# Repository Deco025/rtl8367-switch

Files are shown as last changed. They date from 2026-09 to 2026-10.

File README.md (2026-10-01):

# RTL8367 Switch

**RTL8367RB 五口千兆非网管交换机**





> An open-source five-port gigabit Ethernet switch built around the Realtek RTL8367RB. It is unmanaged: the
> chip boots from strap pins and needs no MCU. Each port has a discrete Pulse H5007NL magnetics module, a shielded RJ45
> and two status LEDs. A 12 V input feeds two on-board bucks, 3.3 V (TPS54331) and 1.1 V (TPS62130A).
> The board is a compact 100 × 72 mm, 4-layer KiCad 10 design, assembled on both sides, with complete fabrication
> outputs.

| 正面（网口一侧） | 背面（电源一侧） |
|---|---|
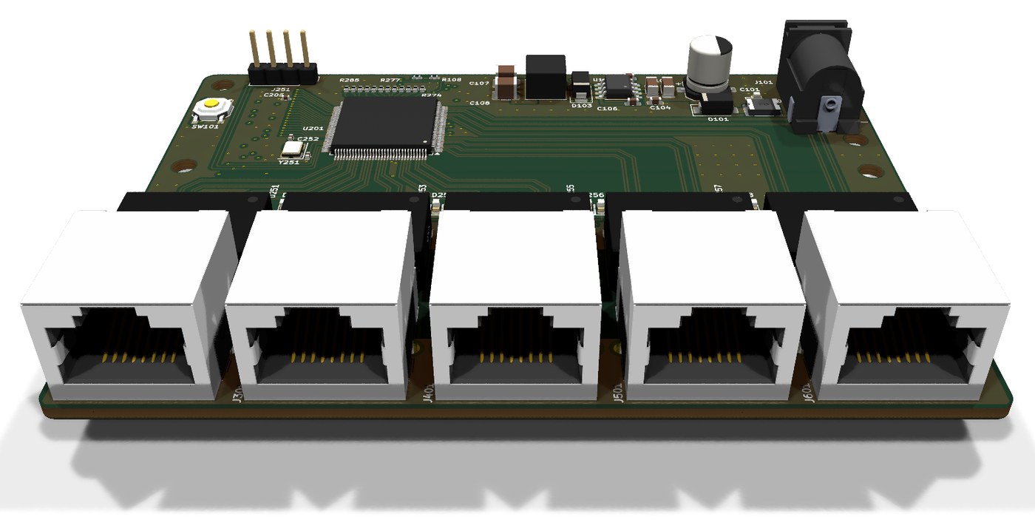
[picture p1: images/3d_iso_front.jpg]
front
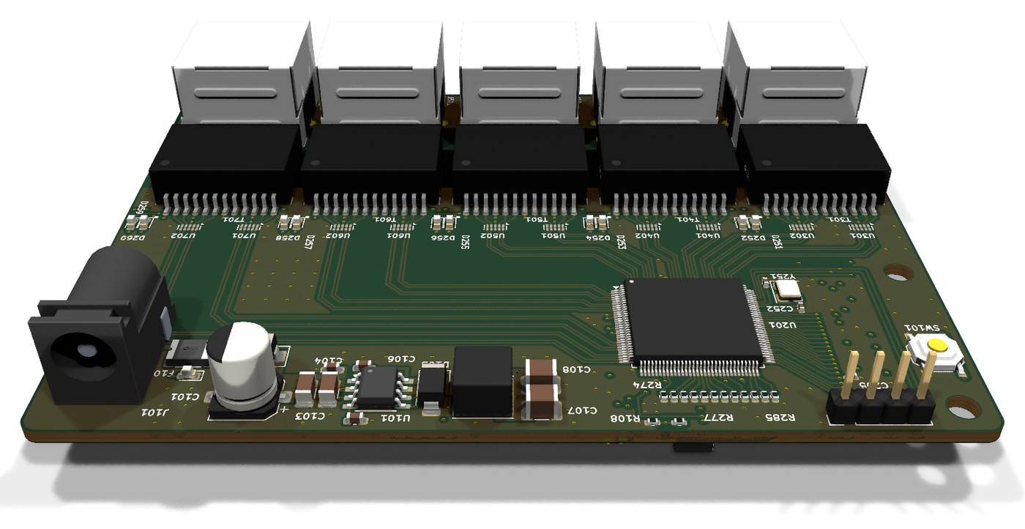
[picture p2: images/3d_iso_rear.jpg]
rear
|  |  |

### PCB 走线

| 顶层 F.Cu | 底层 B.Cu（从背面看） |
|---|---|
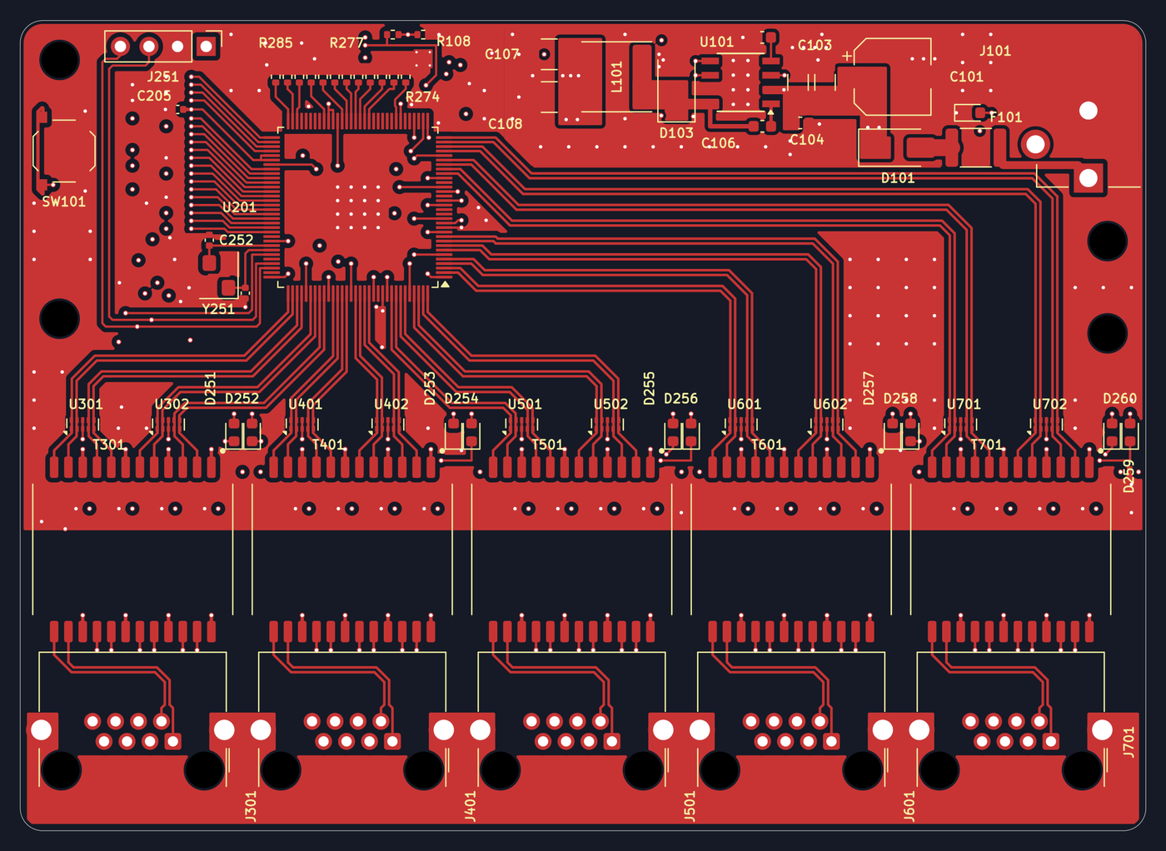
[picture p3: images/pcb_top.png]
top copper
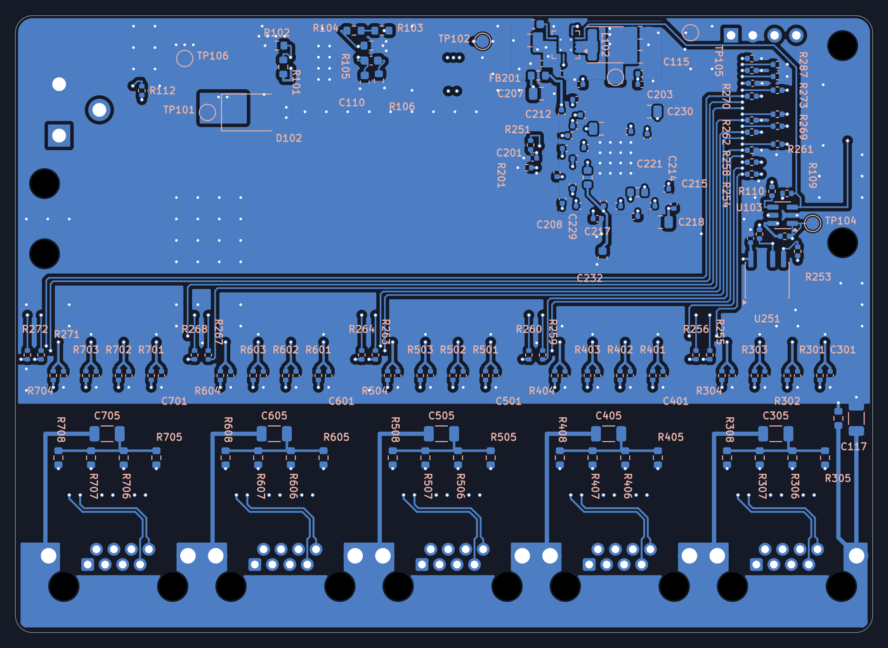
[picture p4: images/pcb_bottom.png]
bottom copper
|  |  |

第 2 层整层是地，第 3 层是电源分区；图里只画了两个外层。

### 前代样机

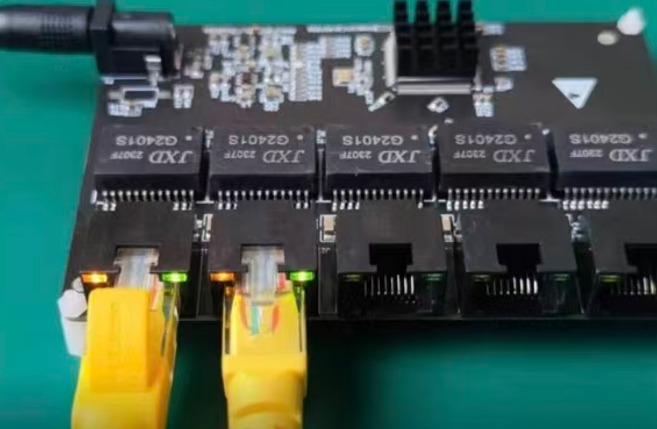
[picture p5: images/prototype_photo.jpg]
前代样机实物


这是本设计的前代样机，已经搭建并通电运行，图中两个网口接线后链路灯亮起。v0.1 在它的基础上重新设计，网络变压器从 JXD G2401S 换成了 Pulse H5007NL。上面的渲染图和走线图都是 v0.1。

---

## 目录

- [主要指标](#主要指标)
- [系统结构](#系统结构)
- [仓库结构](#仓库结构)
- [打开工程](#打开工程)
- [打样与装配](#打样与装配)
- [设计要点](#设计要点)
- [设计检查与装配注意事项](#设计检查与装配注意事项)
- [许可证](#许可证)
- [致谢](#致谢)

## 主要指标

| 项 | 值 |
|---|---|
| 交换芯片 | Realtek RTL8367RB-VB-CG（LQFP-128，带散热焊盘） |
| 端口 | 5 × 10/100/1000BASE-T，RJ45 带屏蔽壳 |
| 管理 | 非网管，靠 strap 引脚配置；预留 SMI 调试口（J251）和 EEPROM 位置（默认不贴） |
| 网络变压器 | Pulse H5007NL × 5（每口一颗，分立） |
| 指示灯 | 每口一绿一黄，外加一颗电源灯 |
| 输入 | 12 V DC，5.5 × 2.1 mm 插座（CUI PJ-102AH） |
| 输入保护 | 自恢复保险丝 0.75 A（1812L075/33DR）、防反接肖特基 SS34、TVS SMBJ15A |
| 3.3 V | TPS54331 降压，6.8 µH，SS34 续流 |
| 1.1 V（芯片核心） | TPS62130A 降压，2.2 µH，放在背面，紧靠芯片 |
| 复位 | TPS3808G30 监控 3.3 V，带手动复位按键 |
| 时钟 | 25 MHz 晶体 |
| PCB | 100 × 72 mm，4 层，1.58 mm，嘉立创叠层 JLC04161H-3313A（外层 1 oz，内层 0.5 oz） |
| 装配 | 双面贴片：正面 56 个、背面 129 个，共 185 个 |

## 系统结构

```mermaid
flowchart LR
    DC[12 V 输入<br/>保险丝 · 防反接 · TVS] --> B1[TPS54331<br/>3.3 V]
    B1 --> B2[TPS62130A<br/>1.1 V 核心]
    B1 --> FB[磁珠滤波<br/>3.3 V / 1.1 V 模拟与 PLL]
    B1 --> RST[TPS3808<br/>复位监控]
    B2 --> SW
    FB --> SW
    RST --> SW
    X[25 MHz 晶体] --> SW[RTL8367RB<br/>5 口千兆交换]
    SW -- MDI × 4 对 --> T[H5007NL × 5<br/>网络变压器]
    T --> J[RJ45 × 5<br/>Bob Smith 终端到 CHASSIS]
    SW --> LED[LED × 10]
```

- 5 个网口都用芯片内置的 PHY，MDI 从芯片直连变压器，中间没有其他器件。
- 变压器芯片侧的中心抽头各接 0.1 µF 到地，另外预留一个 0 Ω 到 +3V3A 的位置（默认不贴）。
- 线缆侧中心抽头各经 75 Ω 汇到一点，再经 1 nF / 2 kV 接屏蔽地 CHASSIS（Bob Smith 终端）。CHASSIS 与 GND 之间有一颗 1 nF 电容。
- 每对差分线旁预留了 ESD 保护（TPD4E02B04，默认不贴）。

更完整的说明见 [docs/design.md](docs/design.md)。

## 仓库结构

```
.
├── rtl8367-switch.kicad_pro   KiCad 工程
├── *.kicad_sch                原理图：根页 + 电源、芯片供电、芯片控制、5 个网口
├── rtl8367-switch.kicad_pcb   PCB
├── lib/                       工程自带的符号和封装（RTL8367RB、H5007NL、RJ45）
├── fab/                       生产文件（Gerber zip、BOM、坐标、装配图、DRC 报告）
├── 3dmodels/                  第三方 3D 模型的来源清单（模型文件不随仓库分发）
├── docs/
│   ├── design.md              设计说明
│   └── schematics/            原理图 PDF（不装 KiCad 也能看）
├── images/                    渲染图和走线图
├── CHANGELOG.md
└── LICENSE                    CERN-OHL-S-2.0
```

## 打开工程

1. 安装 [KiCad](https://www.kicad.org/) **10.0** 或更新版本。
2. 打开 `rtl8367-switch.kicad_pro`。RTL8367RB、H5007NL 和 RJ45 的符号与封装在 `lib/` 里，工程的库表已经指向它们；其余来自 KiCad 官方库。
3. **3D 模型（可选）**：有 6 种器件的 3D 模型不在 KiCad 官方库里，版权也不允许随仓库再分发。按 [3dmodels/README.md](3dmodels/README.md) 下载到 `3dmodels/`，3D 查看器（`Alt+3`）里就能看到完整外观。不下载也不影响原理图、PCB 和生产文件。

## 打样与装配

生产文件已经导出好，坐标原点在板的左上角：

| 用途 | 文件 |
|---|---|
| 上传给板厂 | [`fab/rtl8367-switch-gerber.zip`](fab/rtl8367-switch-gerber.zip) |
| 物料清单 | [`fab/rtl8367-switch-bom.csv`](fab/rtl8367-switch-bom.csv) |
| 贴片坐标（两面） | [`fab/rtl8367-switch-pos.csv`](fab/rtl8367-switch-pos.csv) |
| 装配图（第 1 页正面，第 2 页背面镜像） | [`fab/rtl8367-switch-assembly.pdf`](fab/rtl8367-switch-assembly.pdf) |
| 下单参数 | [`fab/README.md`](fab/README.md) |

下单要点：

- 4 层，1.6 mm，FR4，**叠层选 JLC04161H-3313A**。差分线的线宽线距是按这个叠层算的 100 Ω，换叠层要重算。
- 最小线宽 / 线距 0.2 / 0.15 mm，过孔 0.45 / 0.3 mm 和 0.6 / 0.3 mm。U102 封装自带 0.2 mm 的散热孔，请确认板厂能做。
- 双面贴片，背面也有器件（大多是去耦电容和上下拉电阻）。
- 变压器之后（线缆侧）的地和电源平面是有意挖空的，保证隔离间距，不要让板厂“补铜”。
- 为了版面整洁，丝印上放不下的一些小阻容位号只保留在装配层（Fab），焊接时请对照装配图。

## 设计要点

- **MDI 直通**：变压器的通道在原理图里重新分配过，芯片到变压器的 20 对差分线全部在顶层直走，不打孔、不交叉，下面是完整的地层。线对的顺序和极性调整放在变压器之后、网口下方那一小段。千兆和 10M 模式下，芯片会自动纠正极性；100M 模式对极性不敏感。
- **电源分区**：第 3 层在芯片下方分成 1.1 V 核心、1.1 V 模拟、3.3 V 模拟几块，其余是 3.3 V 主电源；1.1 V PLL 经磁珠单独供电。每个电源脚旁打一个过孔，直通背面的去耦电容。
- **两个降压电源分开放**：3.3 V 在正面右后角，开关节点铜皮只包芯片 SW 脚、续流二极管和电感，离最近的差分线约 4.6 mm；1.1 V 在背面，紧挨芯片，输入环路（PVIN–C112–PGND）在背面就地闭合，输出经过孔直接进第 3 层的核心电源区。两路的反馈分压器和各自的开关节点之间都隔着两层平面。
- **隔离与屏蔽**：变压器之后（线缆侧）不铺地和电源平面，四个线对分走四层，和芯片侧之间留隔离带；网口屏蔽壳和 Bob Smith 终端单独接 CHASSIS 铺铜。外层地铺铜与差分线保持间距，并用缝合过孔连到地层。

详见 [docs/design.md](docs/design.md)。

## 设计检查与装配注意事项

原理图 ERC 0，PCB DRC 0 错误、0 未连接，原理图与 PCB 一致。装配和调试时请留意：

1. **芯片侧中心抽头**：默认每个抽头接 0.1 µF 到地，同时预留了接 +3V3A 的 0 Ω 位置（接法参考同厂 RTL8211E 的布局指南），可按需要切换。
2. **默认转发配置和 LED 功能**由 strap 决定，可以通过 J251 的 SMI 口读写寄存器确认和调整。
3. **RJ45 的 1 脚方向**请在焊接前对照实物核对。
4. **绿色 LED** 正向压降约 2.8 V，470 Ω 限流下约 1 mA；想要更亮可以减小限流电阻。
5. **复位门限**为 2.79 V，偏低的门限用于避免上电时卡在复位里。
6. **DC 插座**（CUI PJ-102AH）请在下单前按厂家规格书确认货源和额定值。

欢迎提交 Issue 反馈问题或改进建议。

## 许可证

本项目的硬件设计文件（原理图、PCB、生产文件、文档）采用
**[CERN Open Hardware Licence Version 2 – Strongly Reciprocal (CERN-OHL-S-2.0)](LICENSE)**。

简单说：可以自由使用、学习、修改、生产和销售；但如果你发布修改后的设计，或者销售基于它的产品，必须用同样的许可证公开对应的设计源文件。

第三方封装、符号和 3D 模型各自遵循其原始许可，不在本许可证范围内。

## 致谢

- [KiCad](https://www.kicad.org/) 及其官方符号 / 封装 / 3D 库。
- 器件 3D 模型的来源见 [3dmodels/SOURCES.md](3dmodels/SOURCES.md)。

欢迎通过 Issue 反馈问题或提出改进。

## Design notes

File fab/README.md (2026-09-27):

# 生产文件

由 `kicad-cli` 从 `rtl8367-switch.kicad_pcb` 导出，坐标原点 = 板左上角（钻孔/贴片原点）。

## 下单参数

| 项 | 值 |
|---|---|
| 层数 | 4 层 |
| 板厚 | 1.6 mm（叠层实际 1.58 mm），FR4 |
| 叠层 | 嘉立创 **JLC04161H-3313A**：F.Cu / 3313 × 2 / In1（地）/ 1.065 mm 芯板 / In2（电源分区）/ 3313 × 2 / B.Cu。**内层顺序不要调换** |
| 铜厚 | 外层 1 oz，内层 0.5 oz |
| 阻抗 | MDI 差分 100 Ω：0.226 / 0.203 mm（按上面的叠层计算） |
| 尺寸 | 100 × 72 mm |
| 表面处理 | 无铅喷锡 |
| 阻焊 / 丝印 | 绿油 / 白字 |
| 过孔 | 盖油 |
| 最小线宽 / 间距 | 0.2 / 0.15 mm |
| 过孔（外径/孔径） | 0.45/0.3（296 个）、0.6/0.3（69 个） |
| 焊盘孔 | PTH 0.2 mm（U102 封装自带的散热孔，4 个）、0.3 / 0.9 / 1.0 / 1.6 / 1.8 mm；NPTH 3.2 mm（4 个安装孔）、3.25 mm（网口定位柱） |
| 贴片 | 双面：正面 56 个，背面 129 个 |

0.2 mm 的散热孔和 0.15 mm 的间距，下单前请对照所选板厂的工艺能力确认。

## 文件

- `rtl8367-switch-gerber.zip`：上传用，含 11 层 Gerber（X2）、PTH/NPTH 分开的 Excellon 钻孔、`.gbrjob`。
- `gerber/`：同上的散文件，另有钻孔分布图 PDF。
- `rtl8367-switch-bom.csv`：按 值 + 耐压 + 封装 合并；默认不贴的器件（ESD 预留位、EEPROM、中心抽头的 0 Ω 选项等）、安装孔和测试点不在表里。
- `rtl8367-switch-pos.csv`：两面的贴片坐标（mm，原点在板左上角）。用嘉立创贴片时需要按其模板改列名并补立创料号，料号见 [docs/design.md](../docs/design.md)。
- `rtl8367-switch-assembly.pdf`：装配图。第 1 页正面，第 2 页背面（镜像）。丝印上放不下而隐藏的小阻容位号都在这里。
- `rtl8367-switch-drc.rpt`：DRC 报告，0 错误、0 未连接。唯一一条警告是 J101 与库里的封装不一致：DC 插座伸出板边，超出板边的丝印线被有意删掉了。

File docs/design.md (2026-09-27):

# RTL8367 Switch 设计说明

本文记录 v0.1 的设计依据与取舍。

## 1. 关键器件

| 用途 | 型号 | 立创料号 |
|---|---|---|
| 交换芯片 | RTL8367RB-VB-CG（E-Pad LQFP-128） | C2761412 |
| 12 V → 3.3 V | TPS54331DDA + SS34 续流 + 6.8 µH | C90761 |
| 3.3 V → 1.1 V | TPS62130ARGTR + 2.2 µH | C337502 |
| 复位监控 | TPS3808G30DBVR（门限 2.79 V） | C189211 |
| 网络变压器 × 5 | Pulse H5007NL | C6384935 |
| RJ45 × 5 | Ckmtw R-RJ45R08P-B000（无灯，带屏蔽） | C386756 |
| 25 MHz 晶体 | YXC X322525MOB4SI，CL 12 pF | C9006 |
| 绿色 LED × 6 | Lite-On LTST-C193TGKT-5A | C12065 |
| 黄色 LED × 5 | KENTO KT-0603Y | C2287 |
| 输入保护 | 1812L075/33DR、SS34、SMBJ15A | C151170、C8678、C83846 |
| DC 插座 | CUI PJ-102AH（5.5 × 2.1 mm） | 采购前请确认 |

没有选 RTL8367S，是因为 RB 的热阻低得多：θJA 16.5 °C/W，S 是 45 °C/W。

## 2. 供电

```
12 V ─ F101 ─ D101（防反接）─ VIN ─┬─ D102 TVS
                                   └─ TPS54331 ─ +3V3 ─┬─ TPS62130A ─ +1V1（核心）─┬─ FB202 ─ +1V1A
                                                       │                           └─ FB203 ─ +1V1P
                                                       ├─ FB201 ─ +3V3A
                                                       └─ TPS3808 复位监控、LED、EEPROM
```

- 复位：TPS3808 监控 +3V3，1.1 V 降压的 PG、手动复位按键和监控器的 MR 接在同一个网络上，任何一个拉低都会让芯片复位。
- 3.3 V 降压放在正面右后角，按电流方向从右到左排列：插座 → 保险丝 → 防反接二极管 → 输入电容 → TPS54331 → 续流二极管 → 电感 → 输出电容。
  - 铺铜：VIN、SW、输出各一块。SW 铜皮只包芯片 SW 脚、续流二极管和电感。
  - 自举电容跨在芯片下方，两端分别对着 BOOT 脚和 SW 脚。
  - 输入电容、续流二极管、输出电容的地端都就近打一排过孔到第 2 层。
- 1.1 V 降压（TPS62130A，2.5 MHz）放在背面，紧挨芯片。
  - SW2、+1V1、+3V3 各有一小块铺铜，外加一块局部地铺铜，输入环路 PVIN–C112–PGND 在背面就地闭合。
  - 输出经电感下方的过孔进入第 3 层的 +1V1 区。
  - 反馈分压器放在正面板边，VOS 和分压器上端在输出过孔处同点采样。

## 3. 叠层与规则

| 层 | 用途 | 厚度 |
|---|---|---|
| F.Cu | 信号：MDI 全部在这层；大件 | 1 oz |
| 预浸料 | 3313 × 2 | 0.107 + 0.0994 mm |
| In1.Cu | 整层地（芯片侧） | 0.5 oz |
| 芯板 | | 1.065 mm |
| In2.Cu | 电源分区 | 0.5 oz |
| 预浸料 | 3313 × 2 | 0.0994 + 0.107 mm |
| B.Cu | 慢信号、去耦电容、1.1 V 降压 | 1 oz |

- 叠层是嘉立创 JLC04161H-3313A，总厚 1.58 mm。
- MDI 按 100 Ω 差分设计：线宽 0.226 mm、线距 0.203 mm，由嘉立创阻抗计算器按这个叠层算出。
- 最小线宽 0.2 mm；芯片引脚间距只有 0.15 mm，所以电源网络的间距设为 0.15 mm。
- 过孔 0.45 / 0.3 mm；缝合孔 0.6 / 0.3 mm。

## 4. 布局

- 5 个网口沿前边排列，间距 19.5 mm，板宽由此决定。
- 每个网口正后方是它的变压器，变压器后面是这个口的两颗 LED；芯片侧中心抽头的电容在变压器后面的背面，线缆侧的 Bob Smith 电阻和电容在变压器与网口之间的背面。
- 交换芯片居中，在变压器后面，晶体在芯片左侧，电源在后边。
- 双面贴片：大件在正面；去耦电容、上下拉电阻、LED 限流电阻、中心抽头电容、终端电阻和测试点放在背面。

## 5. MDI

- **芯片到变压器**：在原理图里重新分配了每个口变压器 4 个通道和芯片 4 对差分线的对应关系，使 20 对线从芯片引脚到变压器全部在顶层直走，不打孔、不交叉，下面是完整的第 2 层地。
- **线对顺序和极性**：变压器之后、网口下方那一段做换序。
  - 为了不交叉，每对线在网口侧的正负标号做了对调。
  - RTL8367RB 在 1000BASE-T 和 10BASE-T 下会自动纠正线对极性，100BASE-TX 对极性不敏感（数据手册 Pre-0.92，§8.10）。
- **线缆侧**：
  - 四个线对分走四层（A 顶层、B 第 2 层、C 第 3 层、D 底层），直接接到网口的通孔脚。
  - 这一段的地和电源平面全部挖空，与芯片侧之间留隔离带。
- **中心抽头**：
  - 芯片侧每个抽头 0.1 µF 到地，并预留一个 0 Ω 到 +3V3A 的位置（默认不贴）。
  - 线缆侧每个抽头 75 Ω 汇到一点，经 1 nF / 2 kV 接 CHASSIS（Bob Smith 终端）。
- **ESD**：每对线旁预留了 TPD4E02B04（直通式，默认不贴），走线直接穿过它的焊盘。

## 6. 电源完整性

- 第 2 层在芯片侧是整层地。第 3 层在芯片下方分出几个区：
  - +1V1 核心区，并伸出一条 2 mm 宽的“手指”到背面的 1.1 V 降压；
  - +1V1A 环；
  - +3V3A 环（另有一条支路给中心抽头的预留位）；
  - 其余是 +3V3 主电源。
- 芯片的每个电源脚旁都打一个过孔，直通背面的 0402 去耦电容，电容的地端再就近打孔。
- 散热焊盘下的 16 个过孔同时是芯片的主要地回路，背面这块区域不放器件。
- 外层在平面范围内铺地，离其他铜 0.4 mm，并打缝合过孔连到第 2 层。

## 7. 时钟与控制

- 25 MHz 晶体离 XTAL 脚很近，两颗负载电容直接贴在晶体焊盘旁，晶体下方的焊盘之间有地连接。
- 扩展口（RGMII）引脚的下拉电阻排成一行，放在芯片后方。
- 10 路 LED 信号在背面汇成一组总线，到各口再分出去。
- J251 引出 SMI 的时钟和数据线，加上 3.3 V 和地，用来读写寄存器。
- EEPROM（AT24C256C）的位置已预留，默认不贴。

## 8. 装配与调试注意事项

见 [README](../README.md#设计检查与装配注意事项)。

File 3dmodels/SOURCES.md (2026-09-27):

# 3D 模型来源

下载日期 2026-09-27。来源页没有写许可说明的，标为“来源页未注明”。

| 文件 | 器件 | 来源 | 立创料号 | 许可 |
|---|---|---|---|---|
| `R-RJ45R08P-B000.step` | Ckmtw R-RJ45R08P-B000 | https://www.lcsc.com/product-detail/Ethernet-Connectors-Modular-Connectors-RJ45-RJ11-Ckmtw-R-RJ45R08P-B000_C386756.html（EasyEDA 3D 导出） | C386756 | 来源页未注明 |
| `C6384935_H5007NL.step` | Pulse H5007NL | https://www.lcsc.com/product-detail/Pulse-Transformers_Pulse-Elec-H5007NL_C6384935.html（EasyEDA 3D 导出） | C6384935 | 来源页未注明 |
| `C3096093_PJ-102AH.step` | Same Sky（原 CUI）PJ-102AH | https://www.lcsc.com/product-detail/dc-power-connectors_cui-pj-102ah_C3096093.html（EasyEDA 3D 导出） | C3096093 | 来源页未注明 |
| `TS-1187A.step` | XKB TS-1187A | https://www.lcsc.com/product-detail/C318884.html（EasyEDA 3D 导出） | C318884 | 来源页未注明 |
| `TPS54331DDA.step` | TI TPS54331DDA | https://www.lcsc.com/product-detail/dc-dc-converters_texas-instruments-tps54331ddar_C90761.html（EasyEDA 3D 导出） | C90761 | 来源页未注明 |
| `1812L075_33DR.step` | Littelfuse 1812L075/33DR | https://www.lcsc.com/product-detail/Resettable-Fuses_Littelfuse-1812L075-33DR_C151170.html（EasyEDA 3D 导出） | C151170 | 来源页未注明 |

- H5007NL 另有 Pulse 官方模型，但它的外廓和规格书的尺寸对不上，所以用了与焊盘对位最准的立创模型。
- U102（TPS62130A，VQFN-16 3 × 3 mm）用 KiCad 自带的同尺寸模型 `WQFN-16-1EP_3x3mm_P0.5mm_EP1.68x1.68mm`，不需要下载。

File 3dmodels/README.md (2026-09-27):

# 3D 模型

下面 6 种器件的 3D 模型不在 KiCad 官方 3D 库里。它们来自立创商城，版权归原作者，所以**不随本仓库分发**。

只看原理图、PCB 或出生产文件时，不需要这些模型。想在 3D 查看器里看到完整外观，就按下表下载，**改成表中的文件名**，放进本目录（`3dmodels/`）。板上的封装已经指向这里，对齐参数也已设好。

| 文件名 | 器件 | 位号 | 立创料号 |
|---|---|---|---|
| `R-RJ45R08P-B000.step` | Ckmtw R-RJ45R08P-B000 网口 | J301、J401、J501、J601、J701 | C386756 |
| `C6384935_H5007NL.step` | Pulse H5007NL 网络变压器 | T301、T401、T501、T601、T701 | C6384935 |
| `C3096093_PJ-102AH.step` | PJ-102AH DC 插座 | J101 | C3096093 |
| `TS-1187A.step` | XKB TS-1187A 轻触开关 | SW101 | C318884 |
| `TPS54331DDA.step` | TI TPS54331DDA | U101 | C90761 |
| `1812L075_33DR.step` | Littelfuse 1812L075/33DR 自恢复保险丝 | F101 | C151170 |

- 下载方法：在立创商城打开对应料号页面，从 EasyEDA 的 3D 模型处导出 STEP。也可以用开源工具 [easyeda2kicad](https://github.com/uPesy/easyeda2kicad.py)，例如：`easyeda2kicad --3d --lcsc_id C386756`。
- 链接与许可说明见 [SOURCES.md](SOURCES.md)。

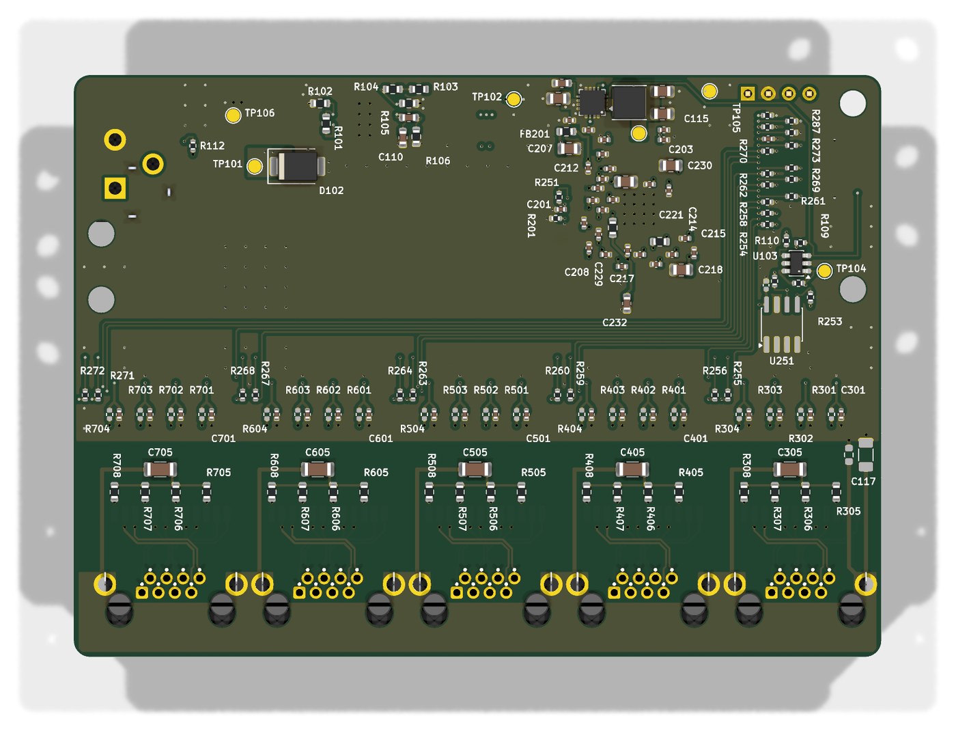
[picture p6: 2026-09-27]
images/3d_bottom.jpg

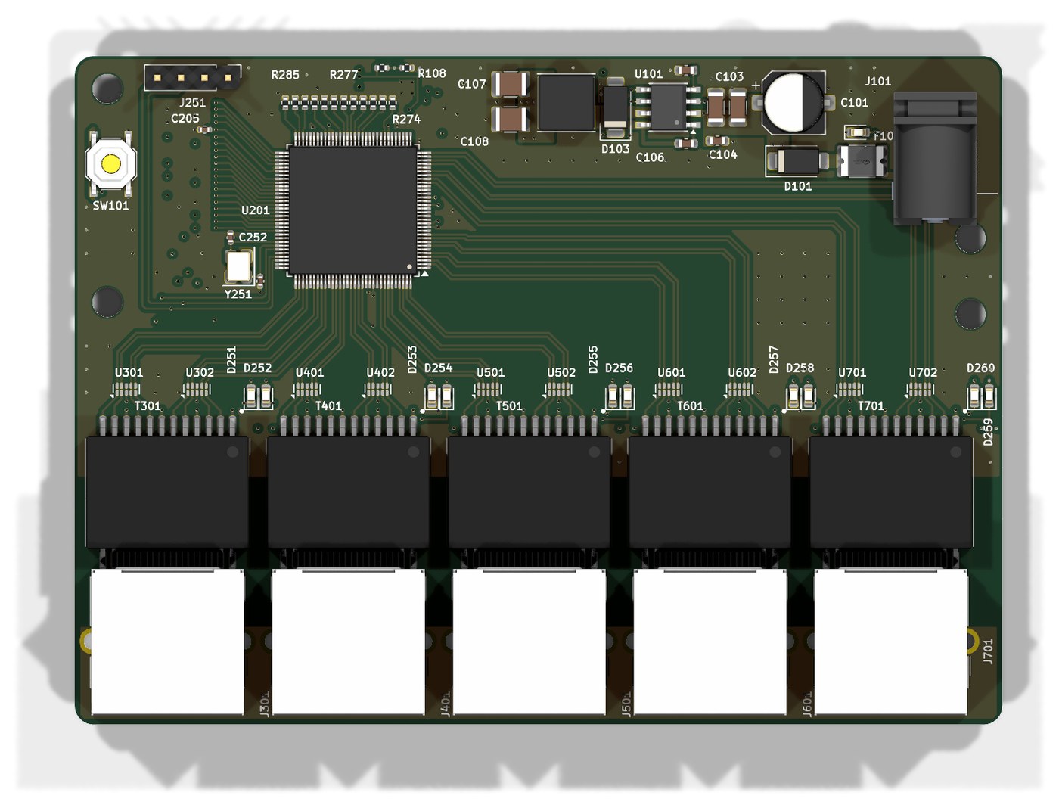
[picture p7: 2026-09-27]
images/3d_top.jpg

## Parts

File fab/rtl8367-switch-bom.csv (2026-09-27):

Refs | Value | Voltage | Footprint | Qty
C101 | 47uF | 25V | Capacitor_SMD:CP_Elec_6.3x7.7 | 1
C102,C103 | 4.7uF | 25V | Capacitor_SMD:C_1206_3216Metric | 2
C104 | 10nF | 50V | Capacitor_SMD:C_0603_1608Metric | 1
C105,C113 | 22nF | 16V | Capacitor_SMD:C_0603_1608Metric | 2
C106 | 100nF | 50V | Capacitor_SMD:C_0603_1608Metric | 1
C107,C108 | 47uF | 10V | Capacitor_SMD:C_1210_3225Metric | 2
C109 | 1nF | 50V | Capacitor_SMD:C_0603_1608Metric | 1
C110 | 47pF | 50V | Capacitor_SMD:C_0603_1608Metric | 1
C111,C207,C218,C222,C230 | 10uF | 10V | Capacitor_SMD:C_0805_2012Metric | 5
C112,C116,C201-C206,C208-C217,C219-C221,C223-C229,C231,C301-C304,C401-C404,C501-C504,C601-C604,C701-C704 | 100nF | 16V | Capacitor_SMD:C_0402_1005Metric | 49
C114,C115 | 22uF | 6.3V | Capacitor_SMD:C_0805_2012Metric | 2
C232 | 1uF | 16V | Capacitor_SMD:C_0603_1608Metric | 1
C251,C252 | 18pF | 50V | Capacitor_SMD:C_0402_1005Metric | 2
C305,C405,C505,C605,C705 | 1nF | 2kV | Capacitor_SMD:C_1206_3216Metric | 5
D101,D103 | SS34 |  | Diode_SMD:D_SMA | 2
D102 | SMBJ15A |  | Diode_SMD:D_SMB | 1
D104,D251,D253,D255,D257,D259 | Green |  | LED_SMD:LED_0603_1608Metric | 6
D252,D254,D256,D258,D260 | Yellow |  | LED_SMD:LED_0603_1608Metric | 5
F101 | 1812L075/33DR |  | Fuse:Fuse_1812_4532Metric | 1
FB201-FB203,R103 | 0R |  | Resistor_SMD:R_0603_1608Metric | 4
J101 | PJ-102AH |  | Connector_BarrelJack:BarrelJack_CUI_PJ-102AH_Horizontal | 1
J251 | J_DBG |  | Connector_PinHeader_2.54mm:PinHeader_1x04_P2.54mm_Vertical | 1
J301,J401,J501,J601,J701 | R-RJ45R08P-B000 |  | rtl8367-switch:RJ45_Ckmtw_R-RJ45R08P-B000_Horizontal | 5
L101 | 6.8uH |  | Inductor_SMD:L_Sunlord_SWPA6045S | 1
L102 | 2.2uH |  | Inductor_SMD:L_Sunlord_SWPA4030S | 1
R101 | 332k |  | Resistor_SMD:R_0603_1608Metric | 1
R102 | 68.1k |  | Resistor_SMD:R_0603_1608Metric | 1
R104 | 10.2k |  | Resistor_SMD:R_0603_1608Metric | 1
R105 | 3.24k |  | Resistor_SMD:R_0603_1608Metric | 1
R106 | 29.4k |  | Resistor_SMD:R_0603_1608Metric | 1
R107 | 30.1k |  | Resistor_SMD:R_0402_1005Metric | 1
R108 | 80.6k |  | Resistor_SMD:R_0402_1005Metric | 1
R109,R111 | 10k |  | Resistor_SMD:R_0402_1005Metric | 2
R110 | 100k |  | Resistor_SMD:R_0402_1005Metric | 1
R112 | 1.5k |  | Resistor_SMD:R_0402_1005Metric | 1
R201 | 2.49k |  | Resistor_SMD:R_0402_1005Metric | 1
R251-R254,R257,R258,R261,R262,R265,R266,R269,R270,R273 | 4.7k |  | Resistor_SMD:R_0402_1005Metric | 13
R255,R256,R259,R260,R263,R264,R267,R268,R271,R272 | 470R |  | Resistor_SMD:R_0402_1005Metric | 10
R274-R289 | 1k |  | Resistor_SMD:R_0402_1005Metric | 16
R305-R308,R405-R408,R505-R508,R605-R608,R705-R708 | 75R |  | Resistor_SMD:R_0603_1608Metric | 20
SW101 | RESET |  | Button_Switch_SMD:SW_Push_1P1T_XKB_TS-1187A | 1
T301,T401,T501,T601,T701 | H5007NL |  | rtl8367-switch:Pulse_H5007NL | 5
U101 | TPS54331DDA |  | Package_SO:Texas_HSOP-8-1EP_3.9x4.9mm_P1.27mm_ThermalVias | 1
U102 | TPS62130A |  | Package_DFN_QFN:VQFN-16-1EP_3x3mm_P0.5mm_EP1.68x1.68mm_ThermalVias | 1
U103 | TPS3808G30DBVR |  | Package_TO_SOT_SMD:SOT-23-6 | 1
U201 | RTL8367RB-VB-CG |  | rtl8367-switch:LQFP-128-1EP_14x14mm_P0.4mm_EP5.5x5.5mm_ThermalVias | 1
Y251 | 25MHz |  | Crystal:Crystal_SMD_3225-4Pin_3.2x2.5mm | 1

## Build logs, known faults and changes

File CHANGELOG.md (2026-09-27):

# 更新日志

## v0.1.0（2026-09-27）

首次发布。

- RTL8367RB 五口千兆非网管交换机的原理图和 4 层 PCB（100 × 72 mm，双面贴片），KiCad 10。
- 原理图 ERC 0；PCB DRC 0 错误、0 未连接；原理图与 PCB 一致。
- 生产文件：Gerber、钻孔、BOM、两面贴片坐标、两页装配图、DRC 报告。
- 原理图 PDF、3D 渲染图和两面走线图。

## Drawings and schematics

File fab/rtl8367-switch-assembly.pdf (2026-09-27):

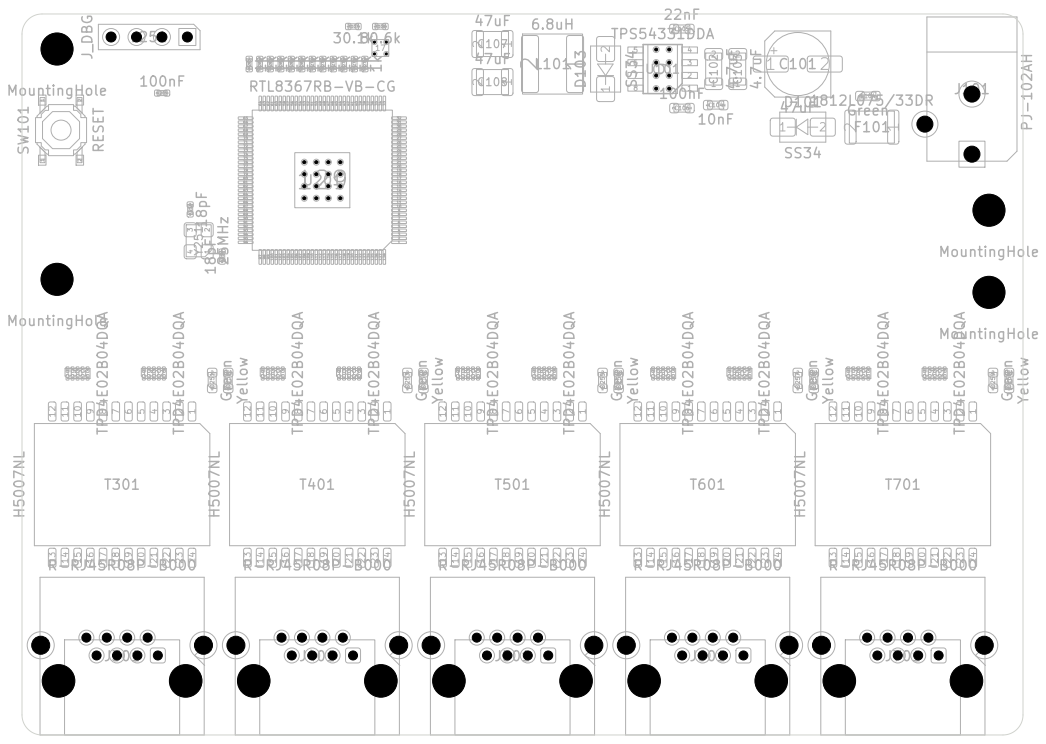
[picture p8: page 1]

Sheet:
File: rtl8367-switch.kicad_pcb
Title: RTL8367RB 5-Port Gigabit Switch

Size: A4 | Rev: 0.1
KiCad E.D.A. 10.0.6 | Id: 1/1

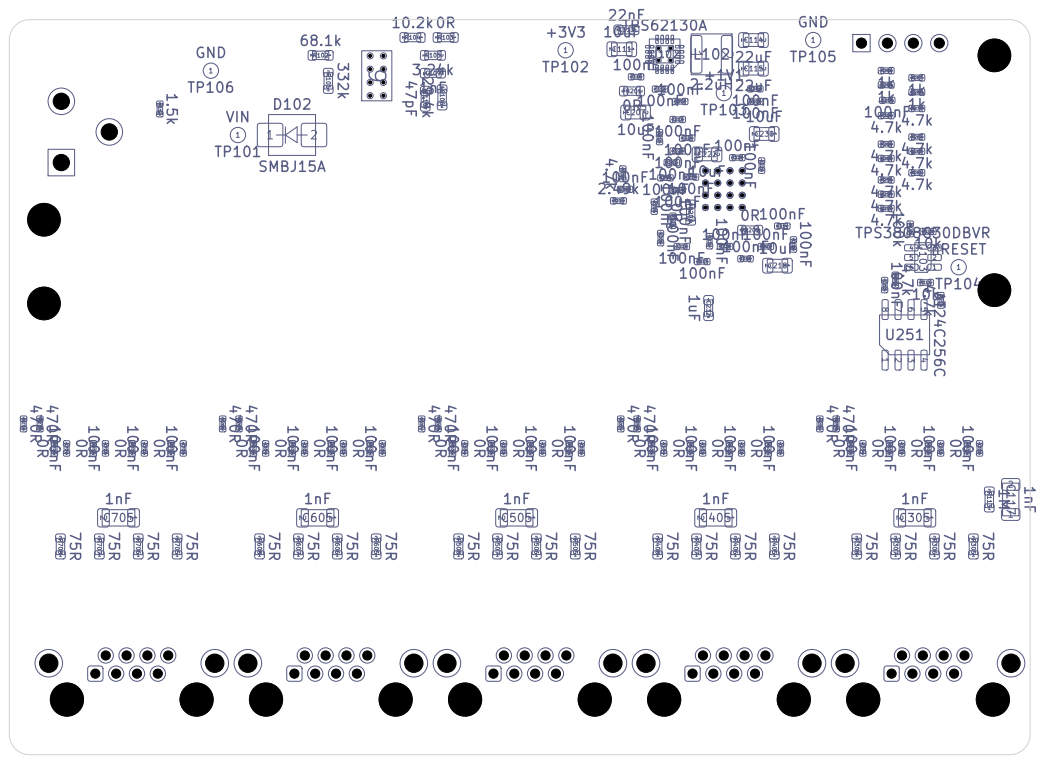
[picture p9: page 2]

Sheet:
File: rtl8367-switch.kicad_pcb
Title: RTL8367RB 5-Port Gigabit Switch

Size: A4 | Rev: 0.1
KiCad E.D.A. 10.0.6 | Id: 1/1

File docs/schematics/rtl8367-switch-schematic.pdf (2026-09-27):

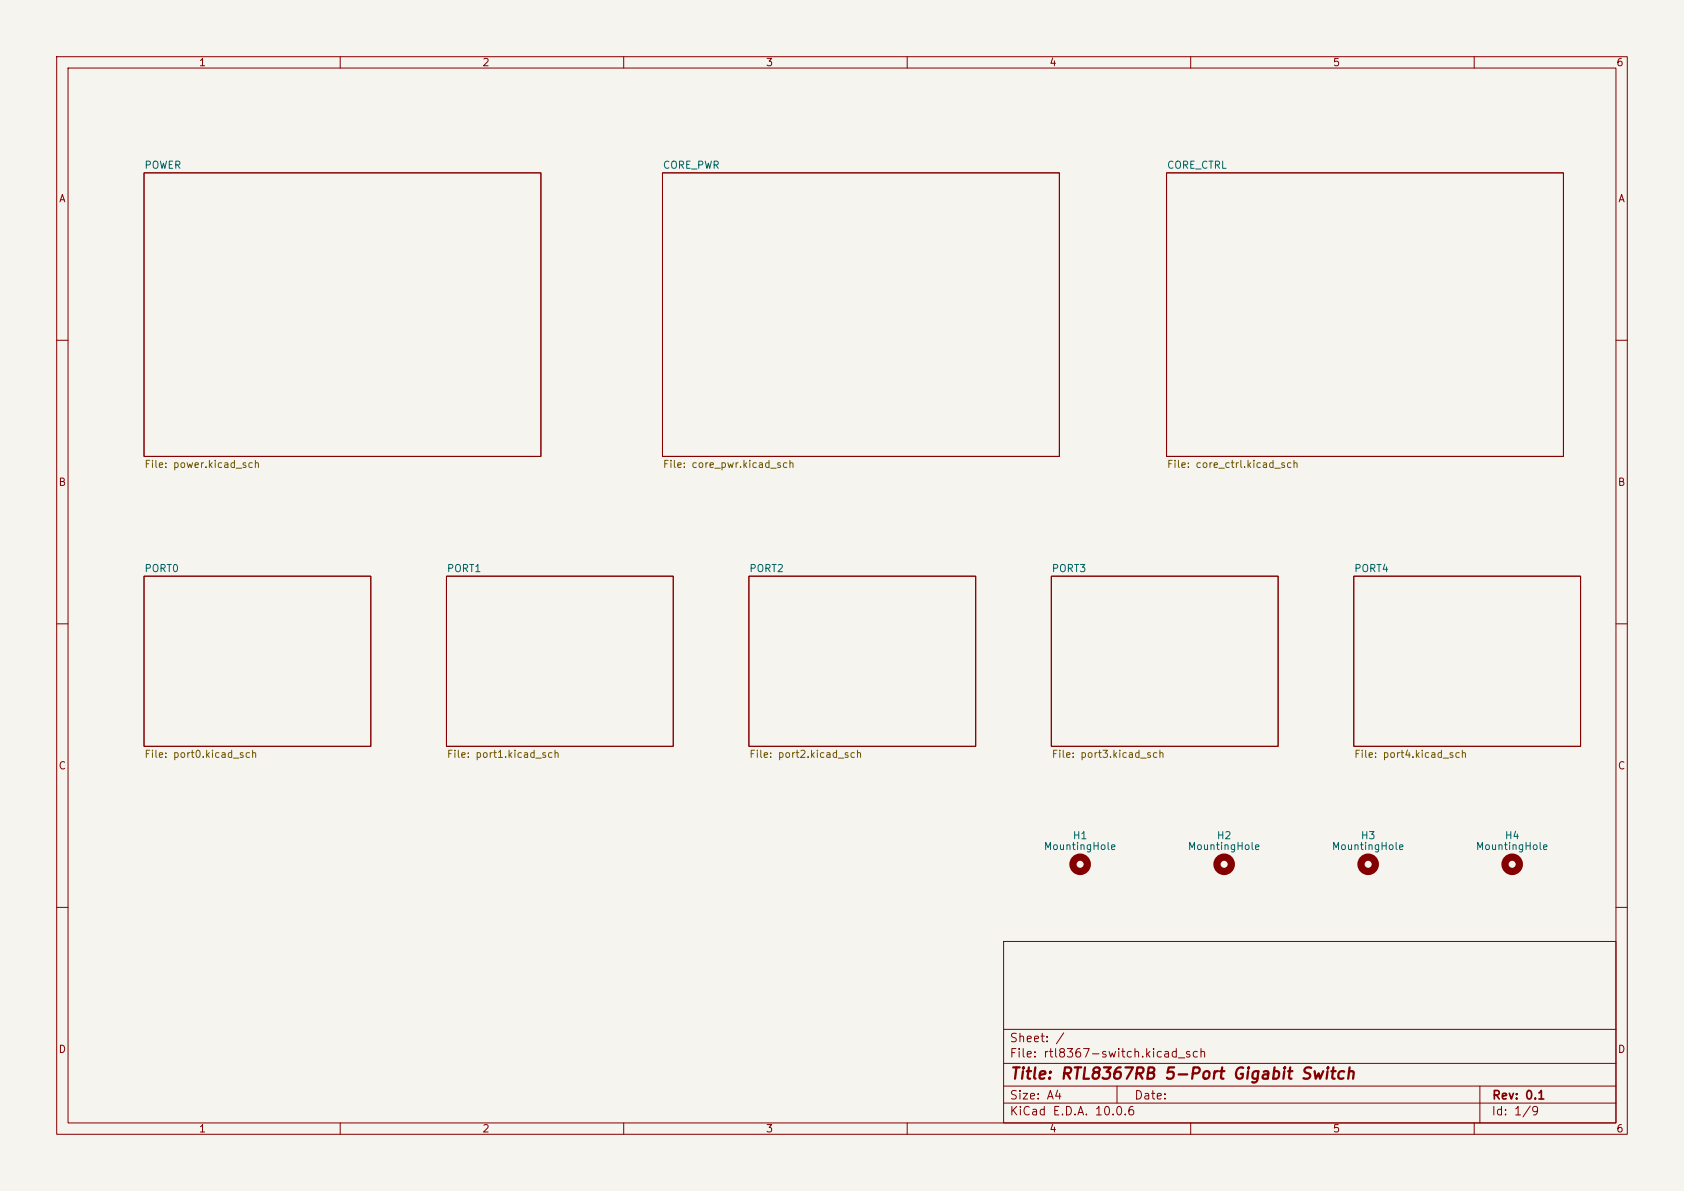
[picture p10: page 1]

Sheet: /
File: rtl8367-switch.kicad_sch
Title: RTL8367RB 5-Port Gigabit Switch

Size: A4 | Rev: 0.1
KiCad E.D.A. 10.0.6 | Id: 1/9

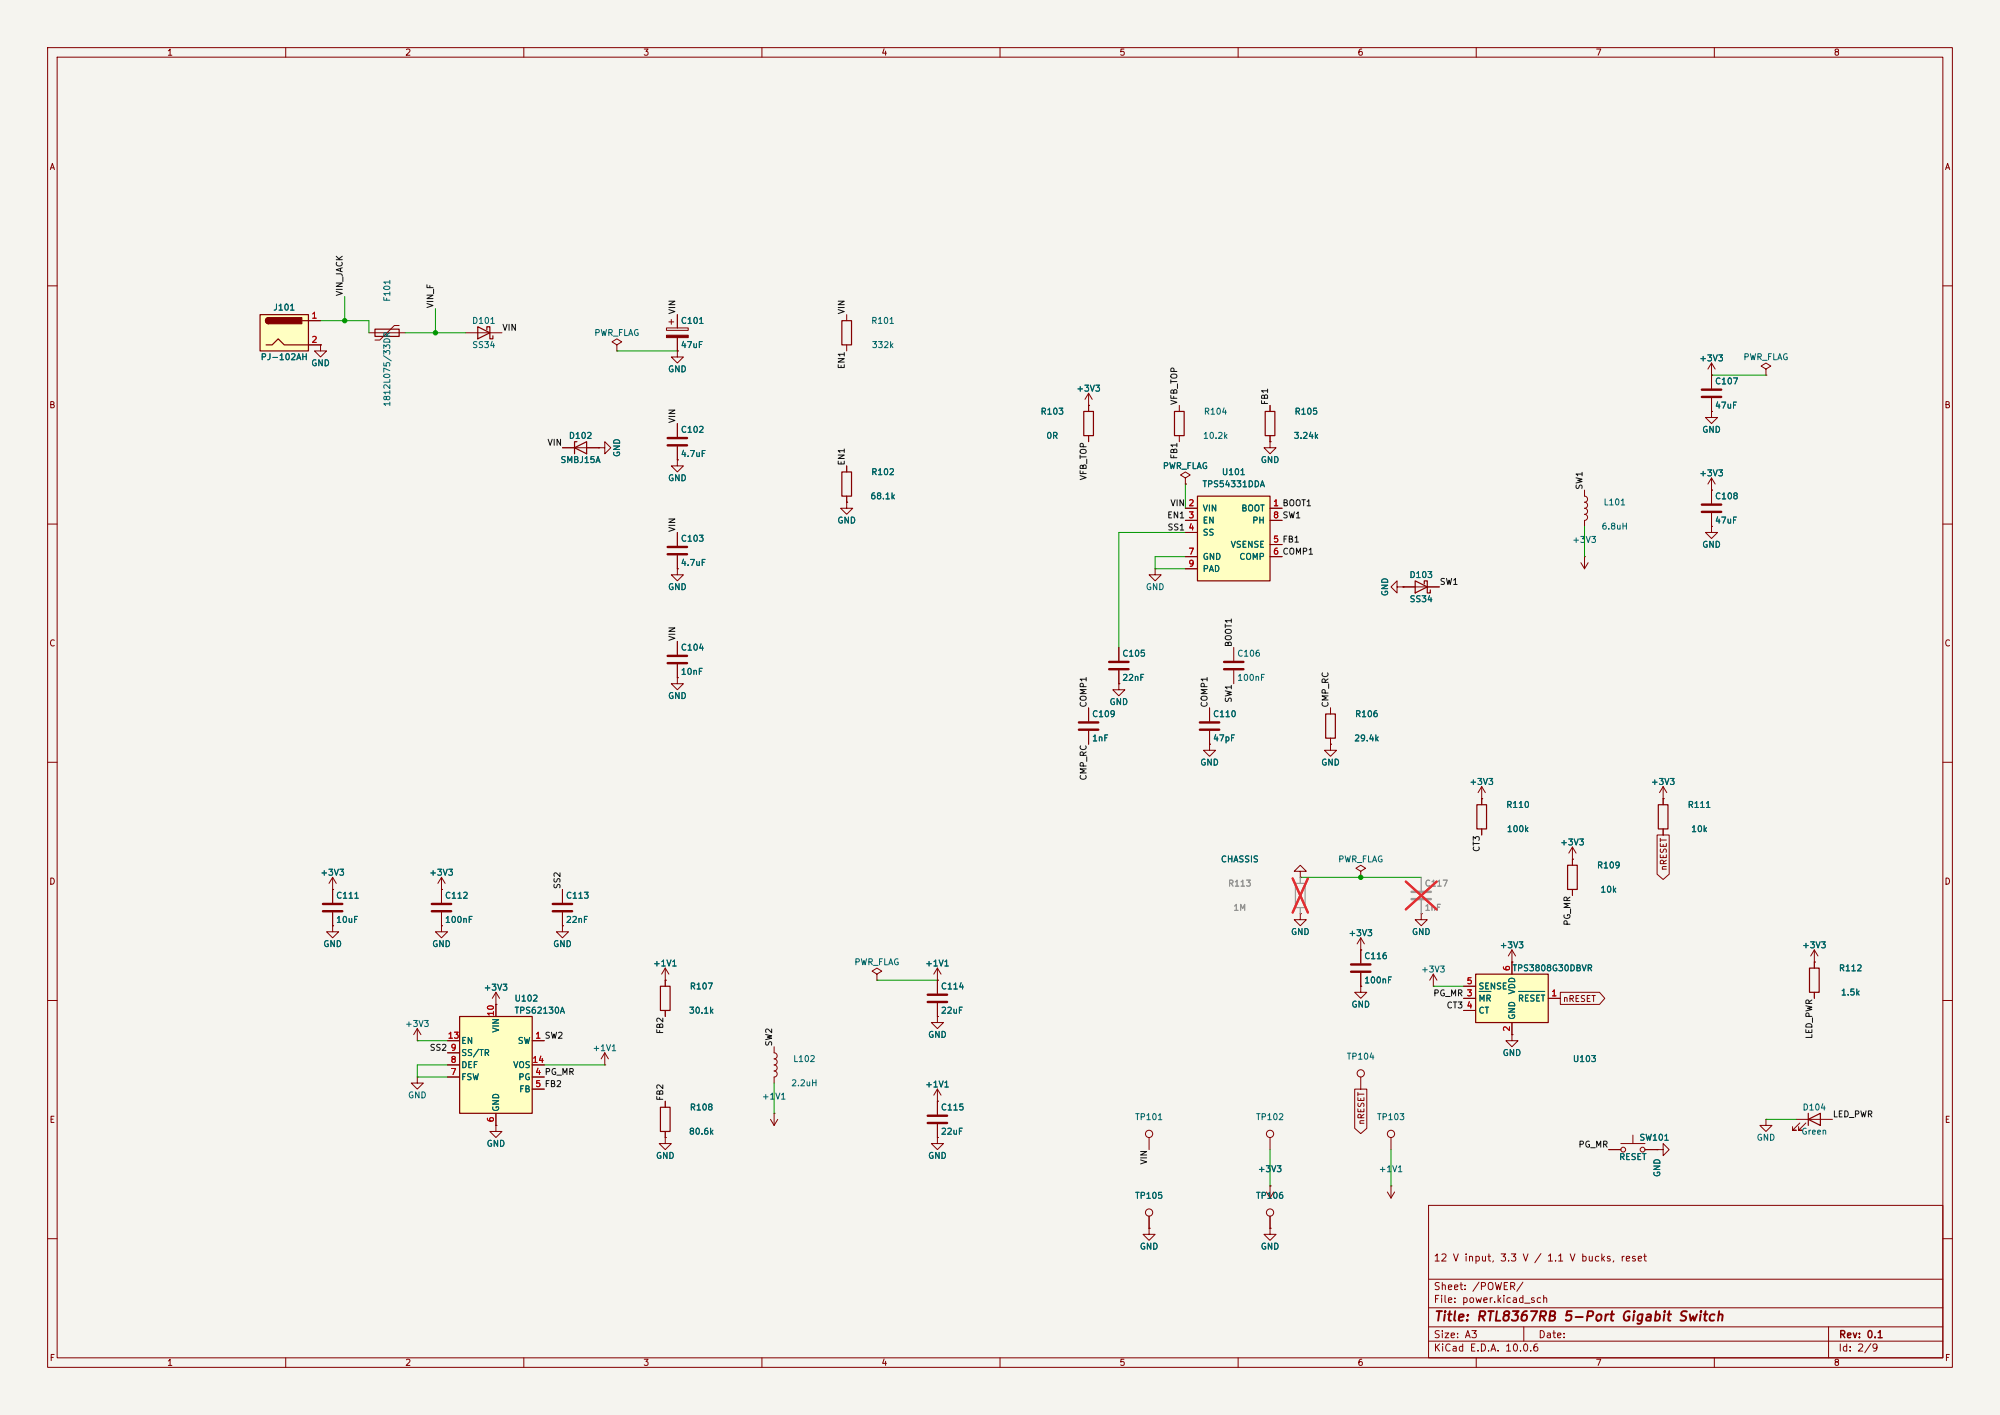
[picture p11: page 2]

12 V input, 3.3 V / 1.1 V bucks, reset +3V3 GND +3V3 GND

Sheet: /POWER/
File: power.kicad_sch
Title: RTL8367RB 5-Port Gigabit Switch

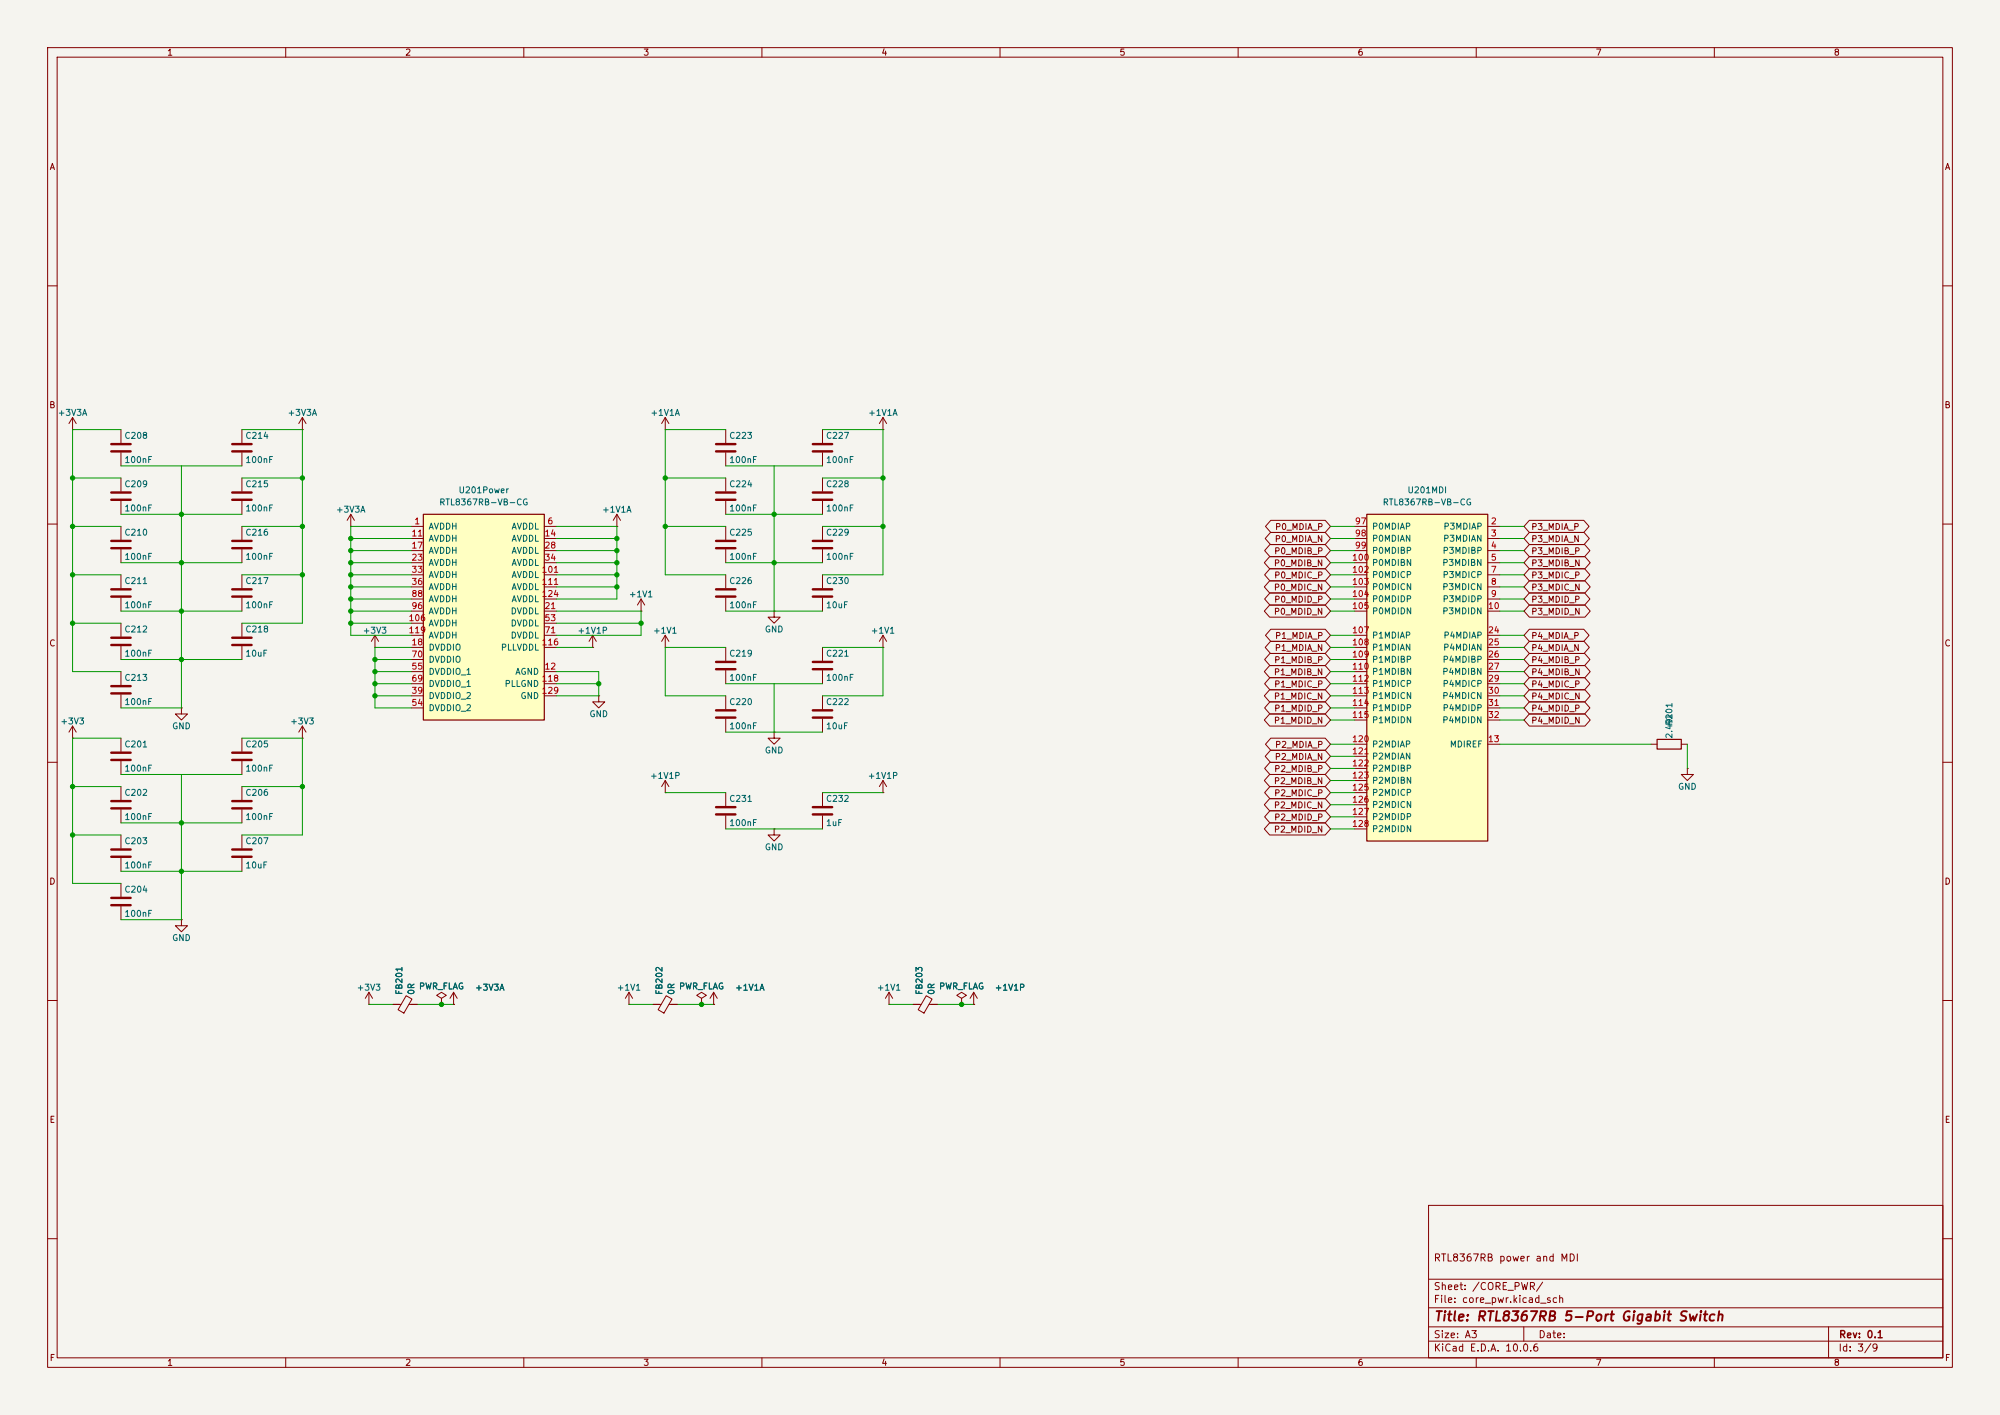
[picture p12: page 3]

Sheet: /CORE_PWR/
File: core_pwr.kicad_sch
Title: RTL8367RB 5-Port Gigabit Switch

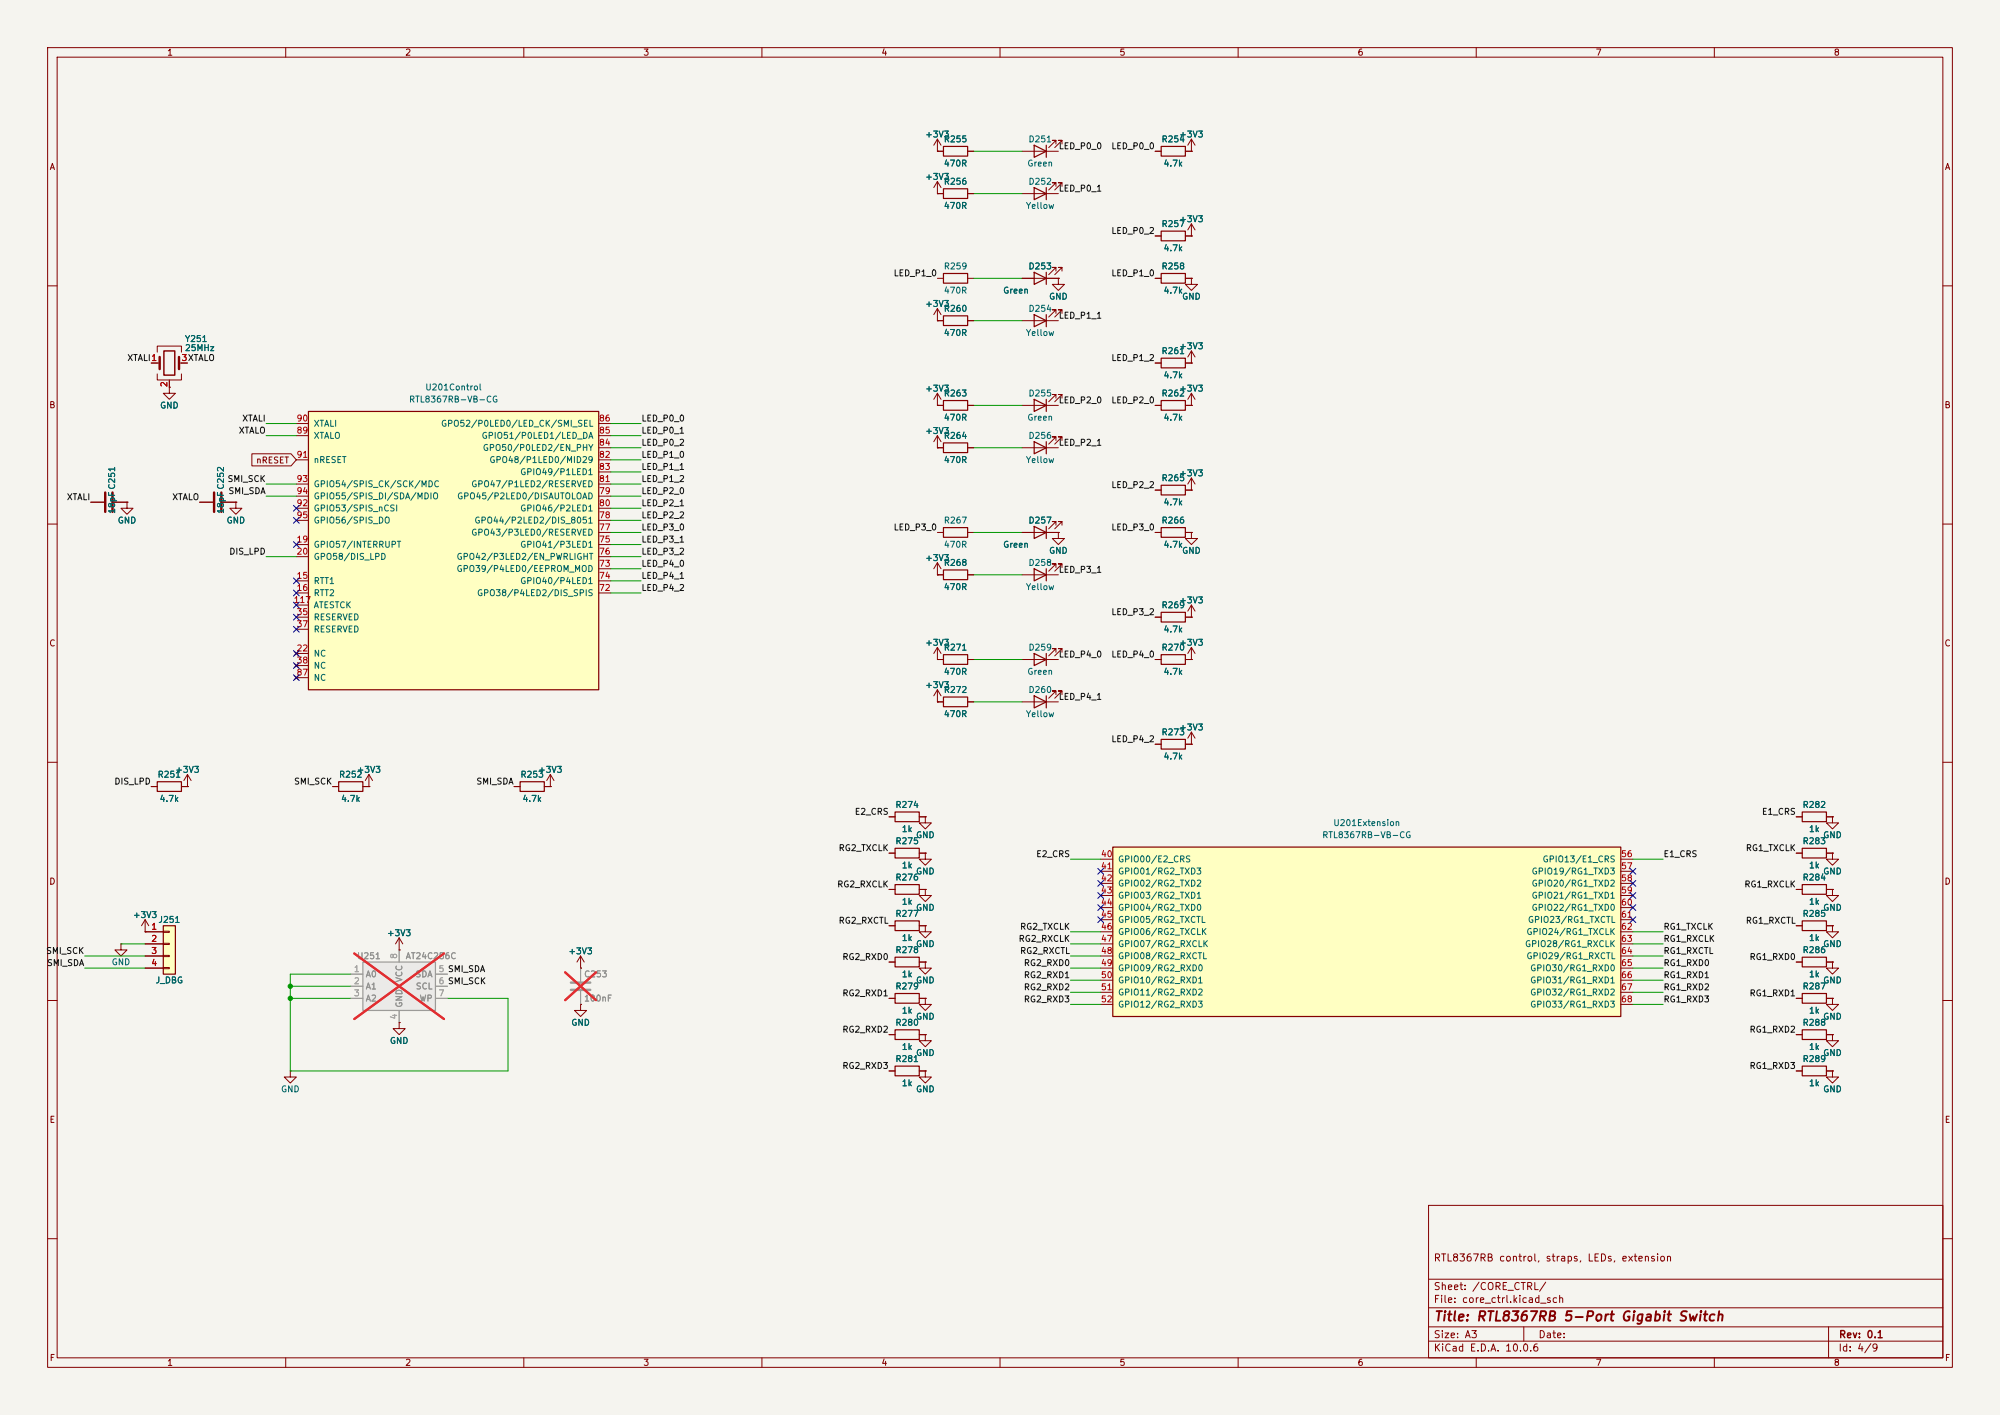
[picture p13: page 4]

RTL8367RB control, straps, LEDs, extension

Sheet: /CORE_CTRL/
File: core_ctrl.kicad_sch
Title: RTL8367RB 5-Port Gigabit Switch

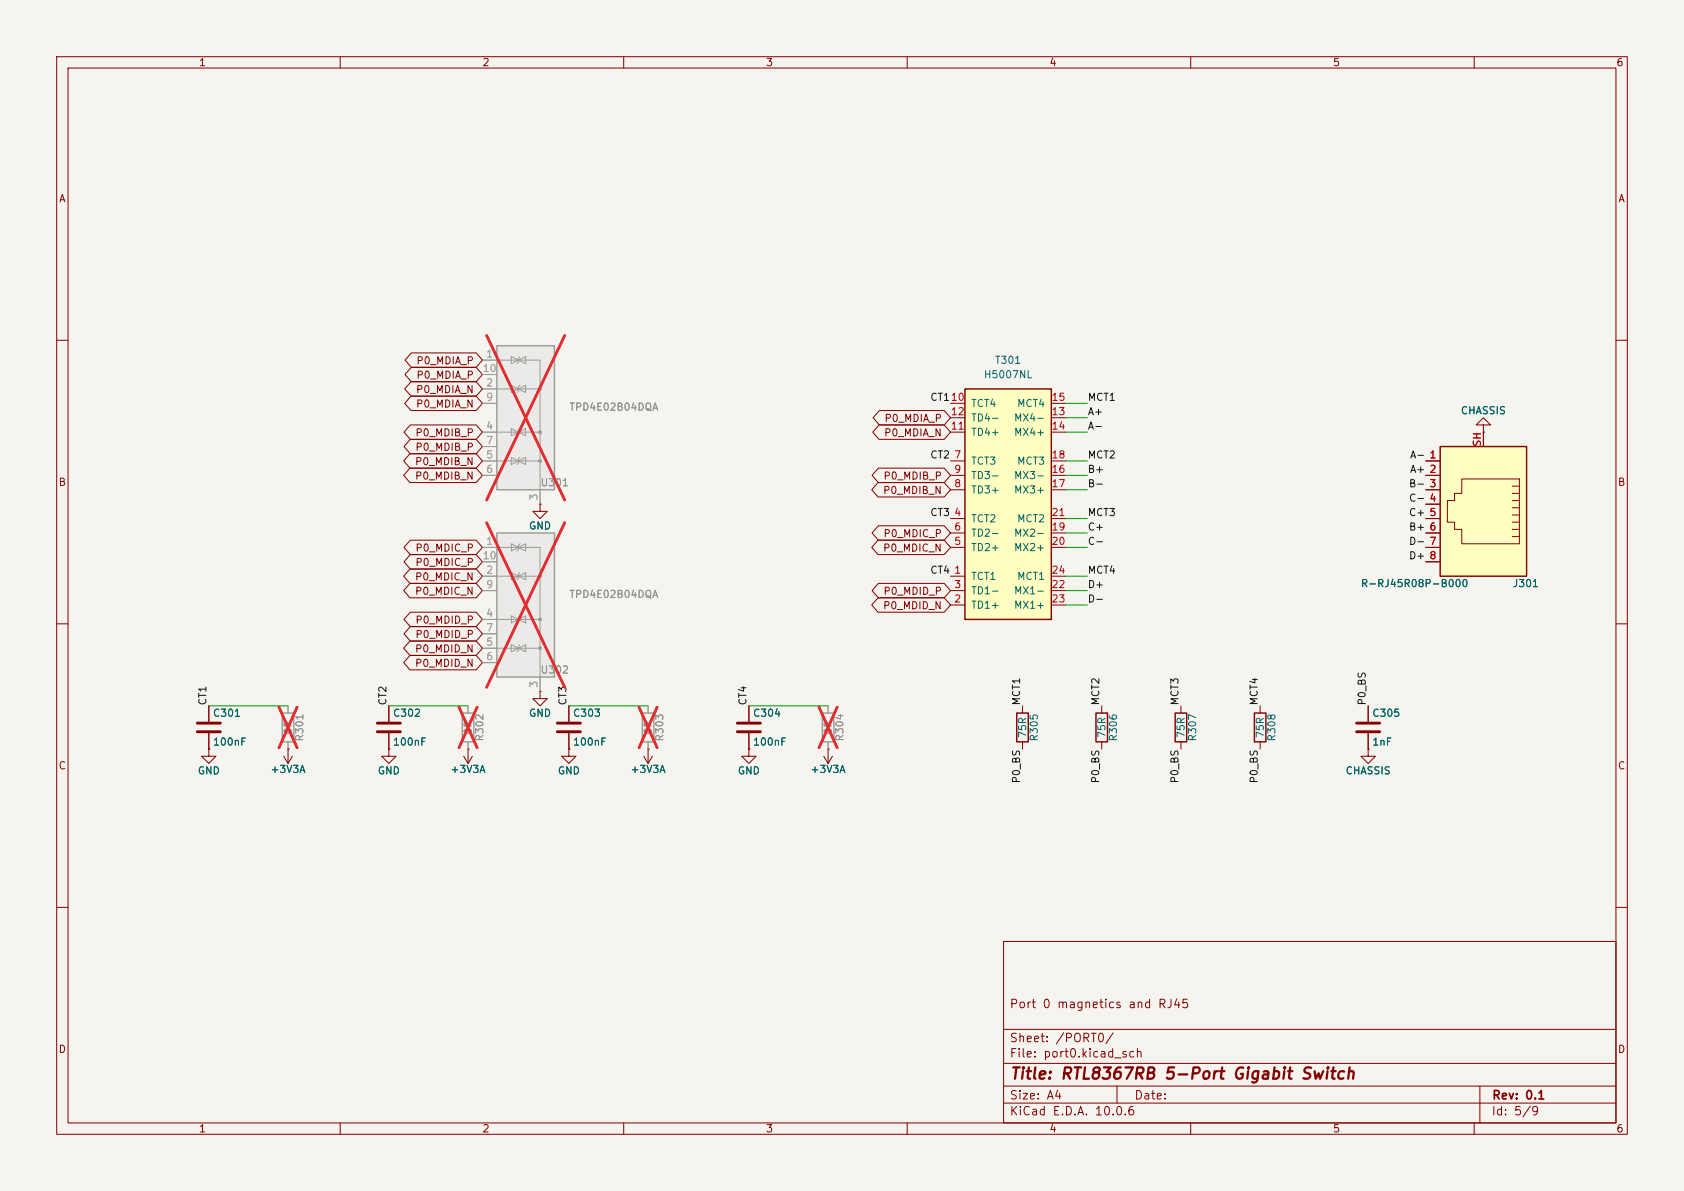
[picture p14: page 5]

Sheet: /PORT0/
File: port0.kicad_sch
Title: RTL8367RB 5-Port Gigabit Switch

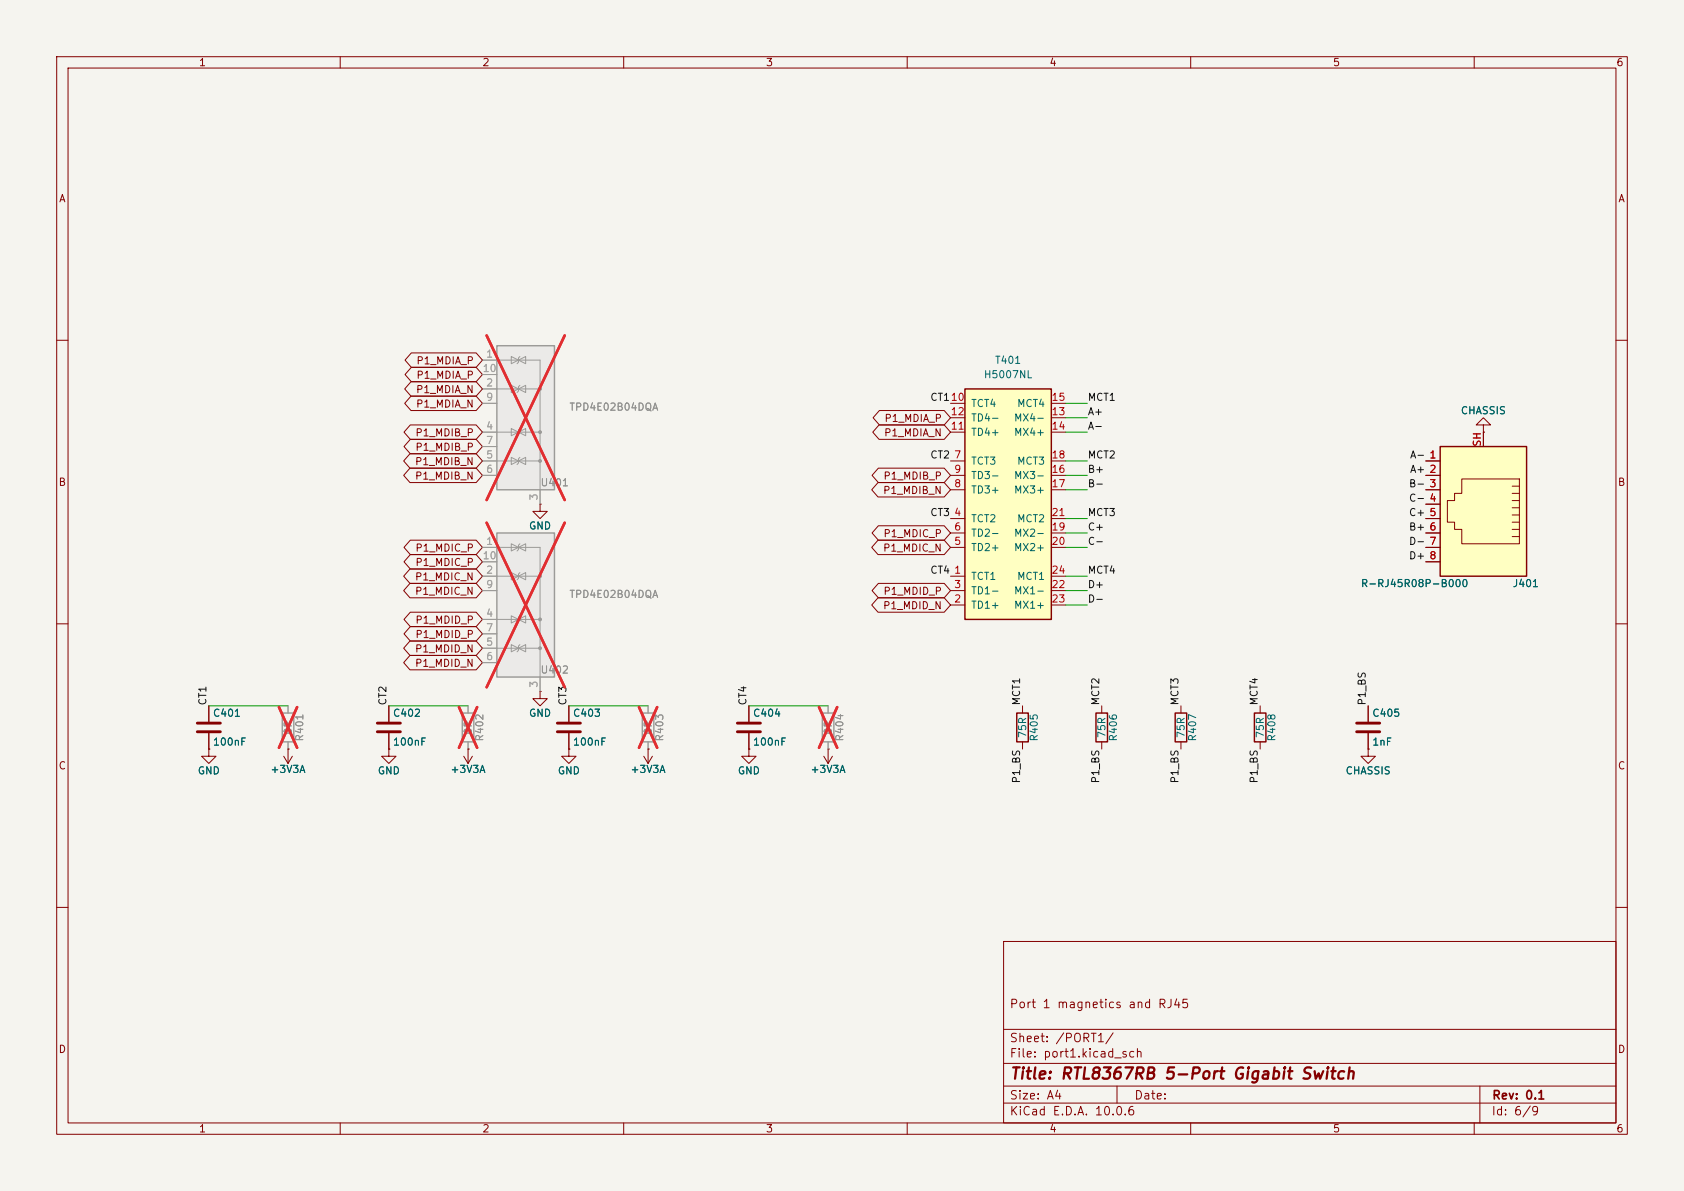
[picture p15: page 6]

Sheet: /PORT1/
File: port1.kicad_sch
Title: RTL8367RB 5-Port Gigabit Switch

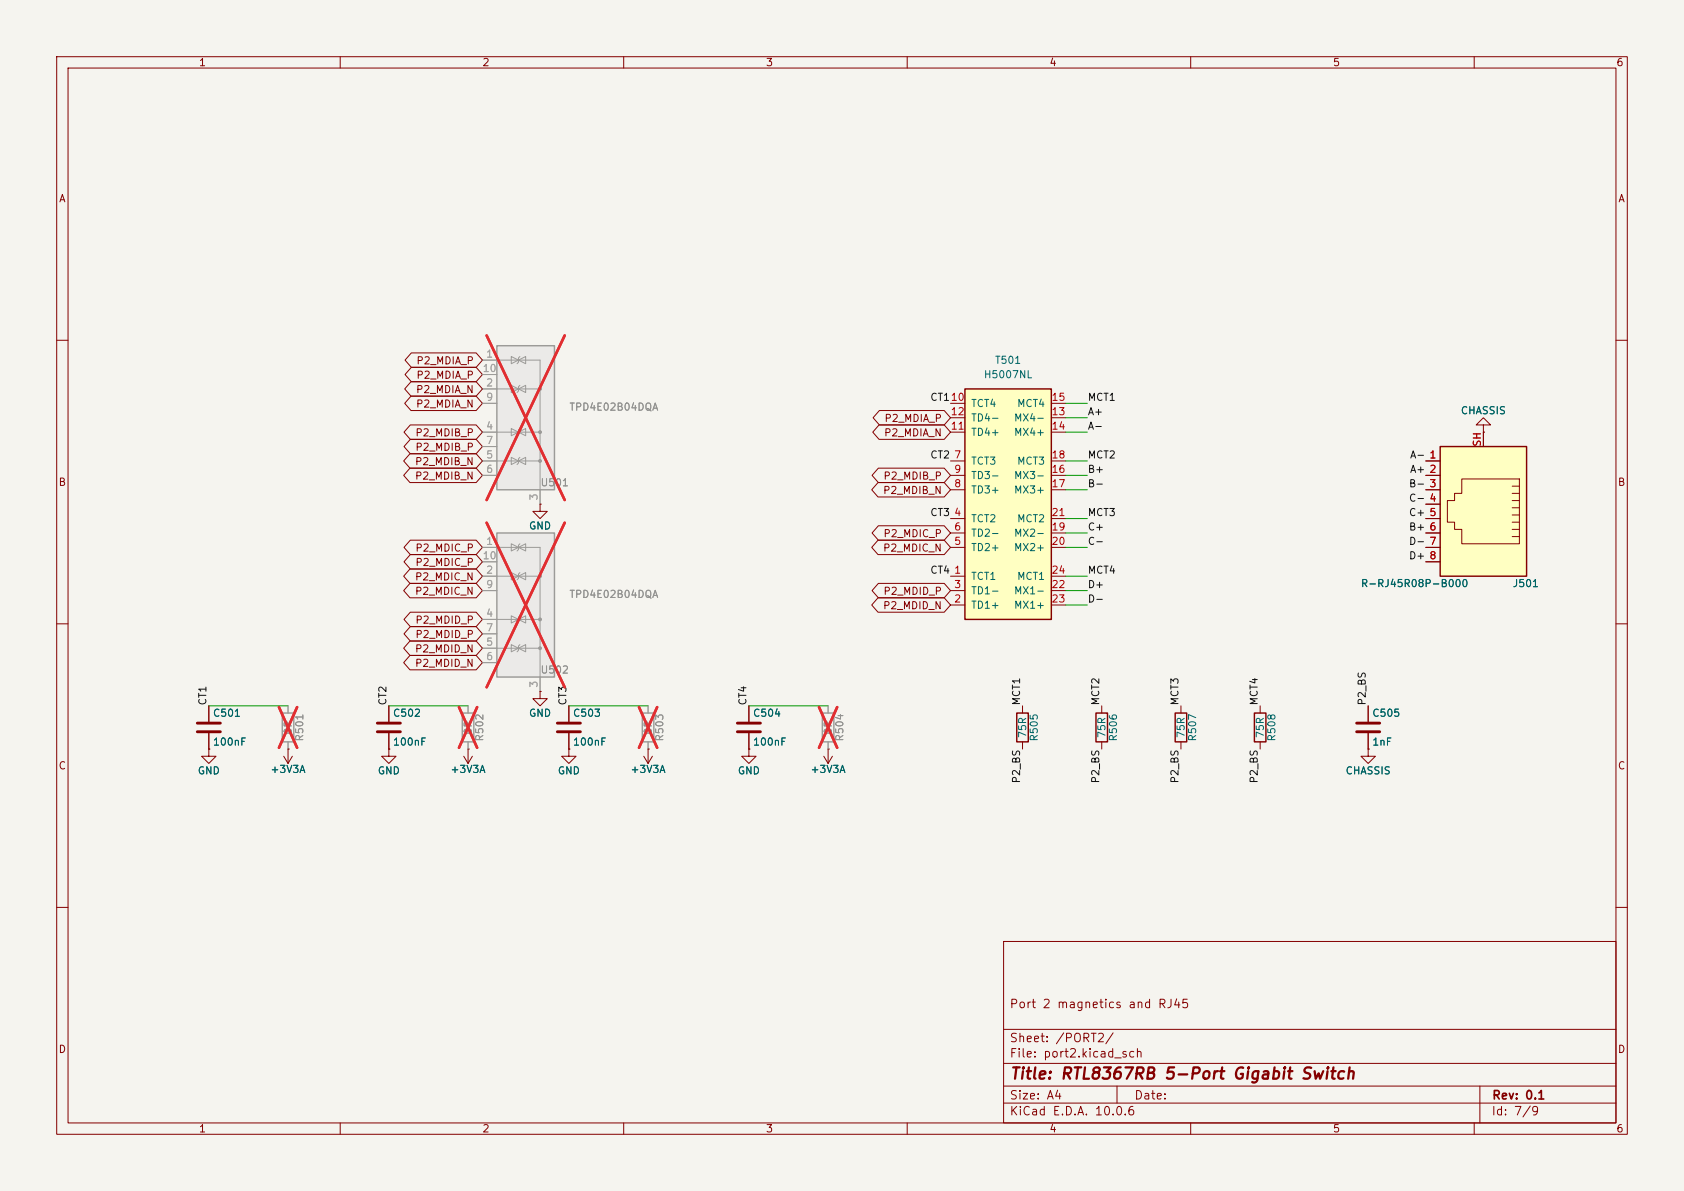
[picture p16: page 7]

Sheet: /PORT2/
File: port2.kicad_sch
Title: RTL8367RB 5-Port Gigabit Switch

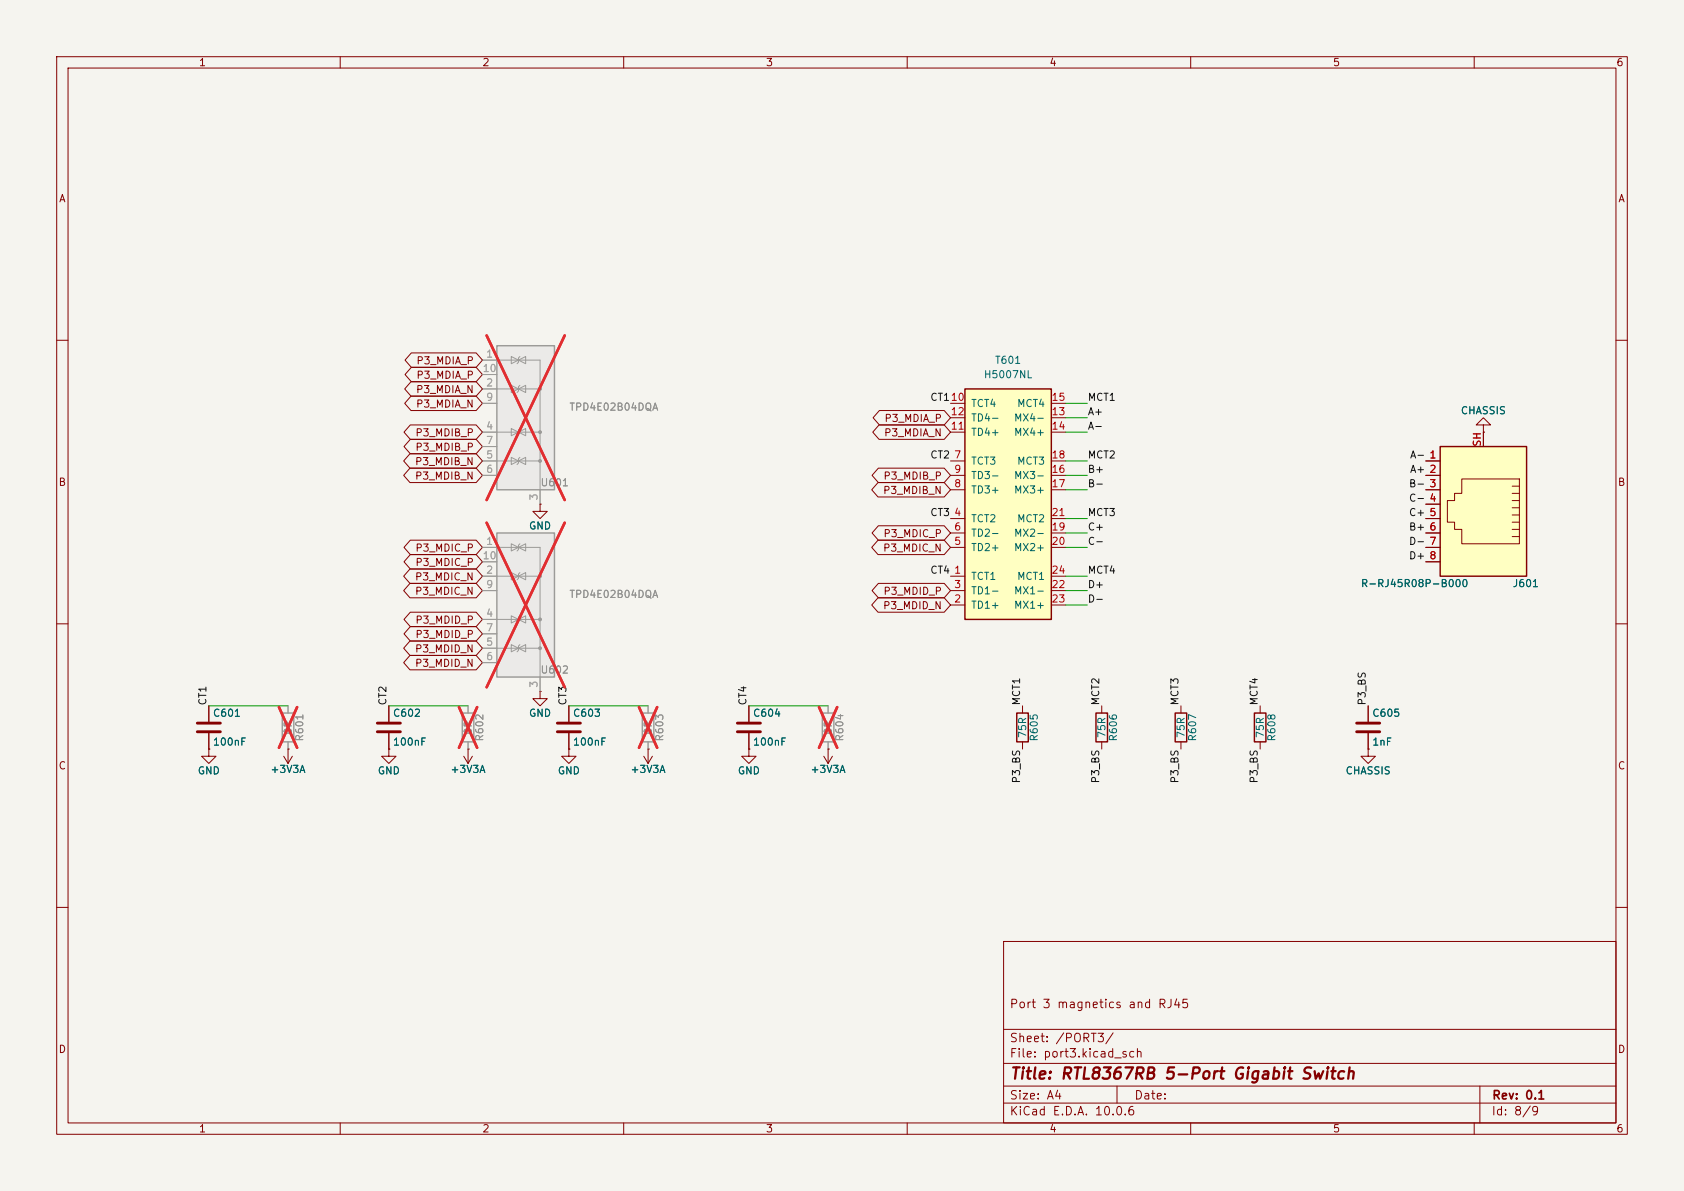
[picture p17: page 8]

Sheet: /PORT3/
File: port3.kicad_sch
Title: RTL8367RB 5-Port Gigabit Switch

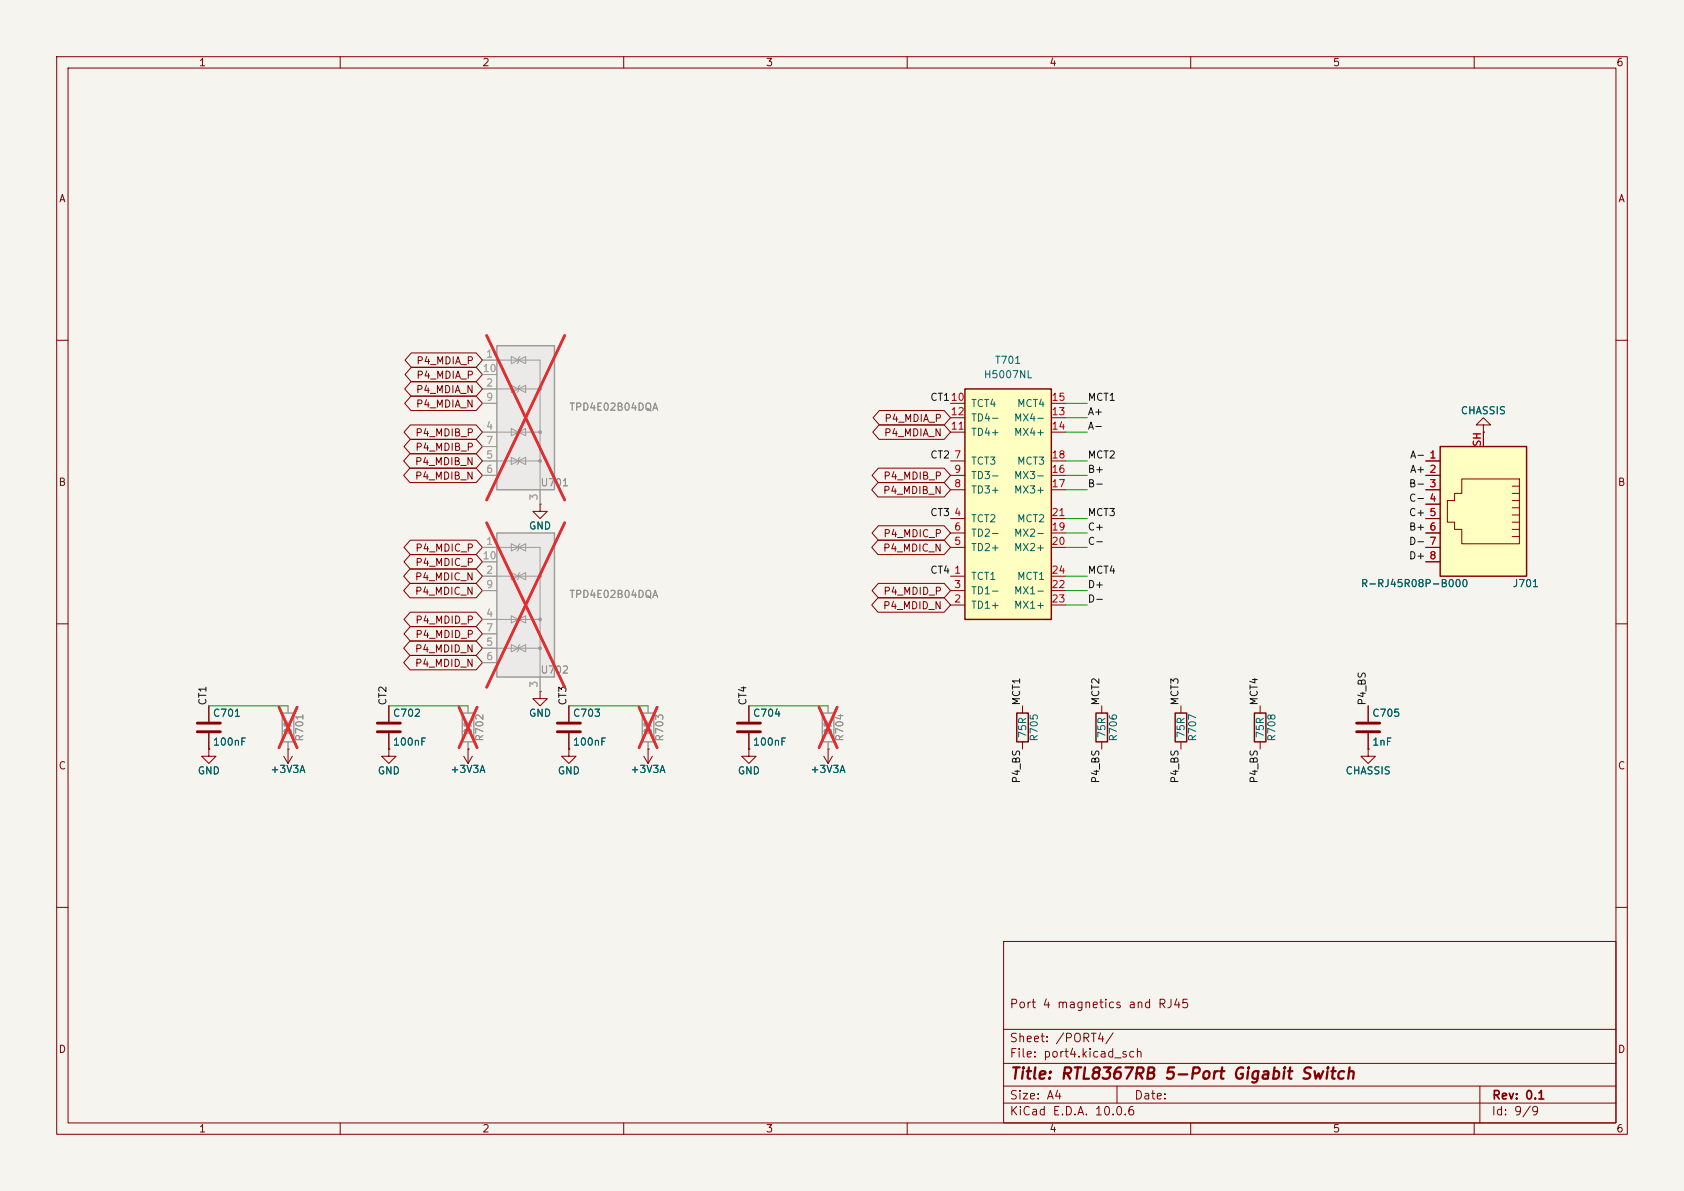
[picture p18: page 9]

Sheet: /PORT4/
File: port4.kicad_sch
Title: RTL8367RB 5-Port Gigabit Switch

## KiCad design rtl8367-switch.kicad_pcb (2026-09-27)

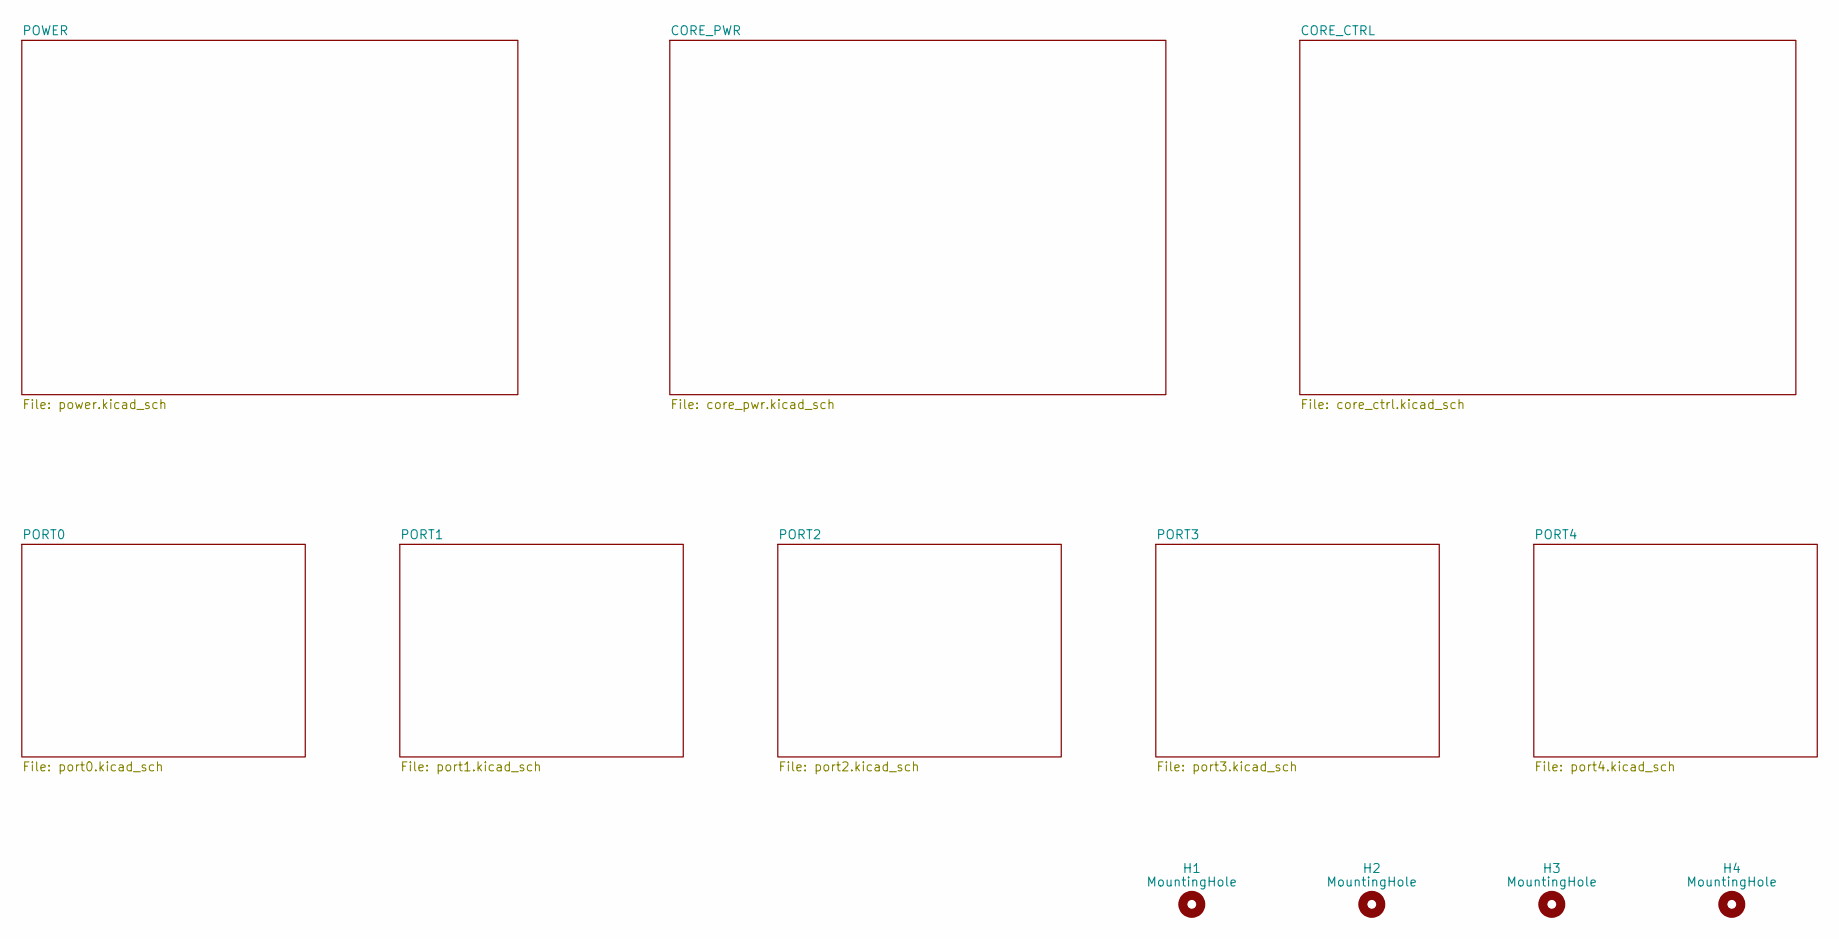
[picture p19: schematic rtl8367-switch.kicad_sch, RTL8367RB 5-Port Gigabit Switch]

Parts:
H1, H2, H3, H4: MountingHole; MountingHole_3.2mm_M3

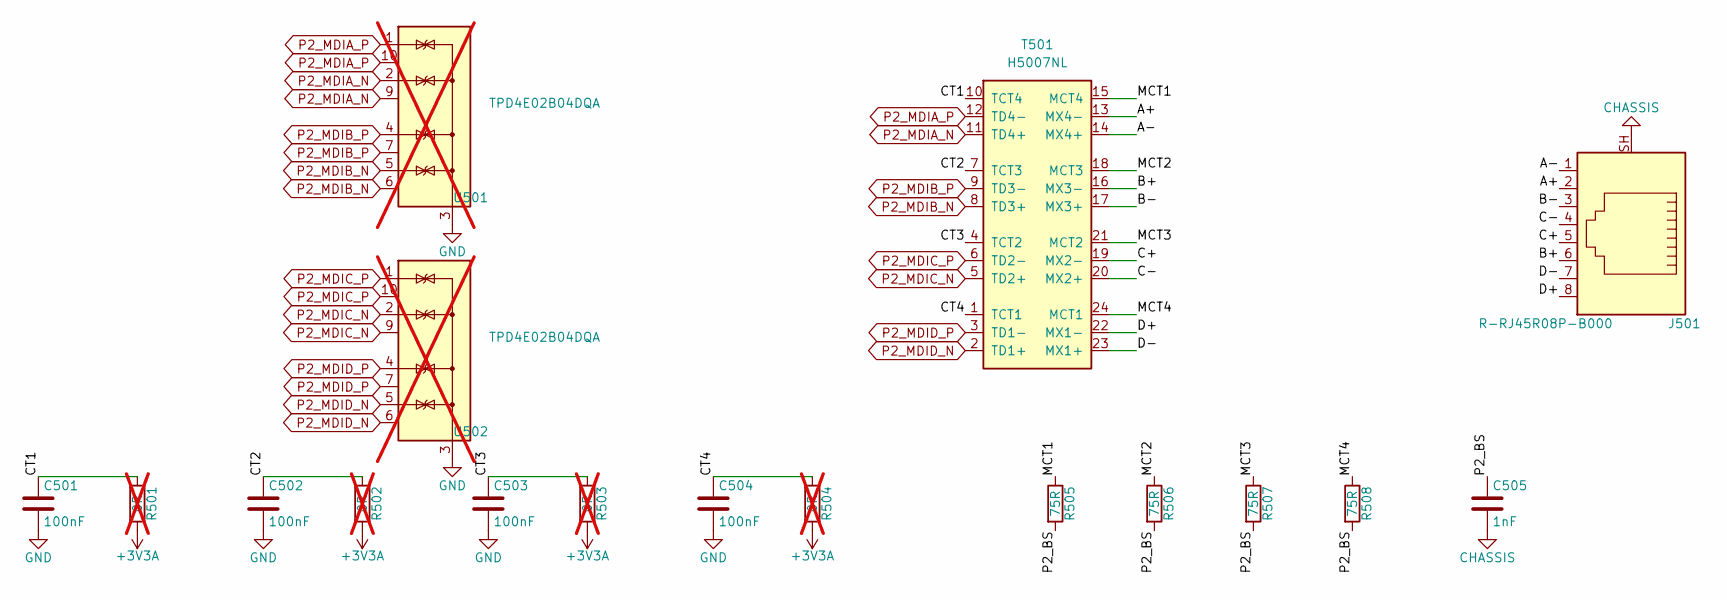
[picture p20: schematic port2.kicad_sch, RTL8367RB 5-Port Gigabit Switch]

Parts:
C501, C502, C503, C504: 100nF; C_0402_1005Metric; Voltage 16V
C505: 1nF; C_1206_3216Metric; Voltage 2kV
J501: R-RJ45R08P-B000; RJ45_Ckmtw_R-RJ45R08P-B000_Horizontal; MPN R-RJ45R08P-B000; LCSC C386756
R501, R502, R503, R504: 0R; R_0402_1005Metric; not fitted
R505, R506, R507, R508: 75R; R_0603_1608Metric; Tolerance 1%
T501: H5007NL; Pulse_H5007NL; MPN H5007NL; LCSC C6384935
U501, U502: TPD4E02B04DQA; USON-10_2.5x1.0mm_P0.5mm; MPN TPD4E02B04DQAR; not fitted

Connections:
+3V3A: R501.2, R502.2, R503.2, R504.2; also elsewhere on the board
/PORT2/A+: J501.2, T501.13 (MX4-)
/PORT2/A-: J501.1, T501.14 (MX4+)
/PORT2/B+: J501.6, T501.16 (MX3-)
/PORT2/B-: J501.3, T501.17 (MX3+)
/PORT2/C+: J501.5, T501.19 (MX2-)
/PORT2/C-: J501.4, T501.20 (MX2+)
/PORT2/CT1: C501.1, R501.1, T501.10 (TCT4)
/PORT2/CT2: C502.1, R502.1, T501.7 (TCT3)
/PORT2/CT3: C503.1, R503.1, T501.4 (TCT2)
/PORT2/CT4: C504.1, R504.1, T501.1 (TCT1)
/PORT2/D+: J501.8, T501.22 (MX1-)
/PORT2/D-: J501.7, T501.23 (MX1+)
/PORT2/MCT1: R505.1, T501.15 (MCT4)
/PORT2/MCT2: R506.1, T501.18 (MCT3)
/PORT2/MCT3: R507.1, T501.21 (MCT2)
/PORT2/MCT4: R508.1, T501.24 (MCT1)
/PORT2/P2_BS: C505.1, R505.2, R506.2, R507.2, R508.2
CHASSIS: C505.2, J501.SH; also elsewhere on the board
GND: C501.2, C502.2, C503.2, C504.2, U501.3 (G), U501.8 (G), U502.3 (G), U502.8 (G); also elsewhere on the board
P2_MDIA_N: T501.11 (TD4+), U501.2 (IO2), U501.9 (NC); also elsewhere on the board
P2_MDIA_P: T501.12 (TD4-), U501.1 (IO1), U501.10 (NC); also elsewhere on the board
P2_MDIB_N: T501.8 (TD3+), U501.5 (IO4), U501.6 (NC); also elsewhere on the board
P2_MDIB_P: T501.9 (TD3-), U501.4 (IO3), U501.7 (NC); also elsewhere on the board
P2_MDIC_N: T501.5 (TD2+), U502.2 (IO2), U502.9 (NC); also elsewhere on the board
P2_MDIC_P: T501.6 (TD2-), U502.1 (IO1), U502.10 (NC); also elsewhere on the board
P2_MDID_N: T501.2 (TD1+), U502.5 (IO4), U502.6 (NC); also elsewhere on the board
P2_MDID_P: T501.3 (TD1-), U502.4 (IO3), U502.7 (NC); also elsewhere on the board

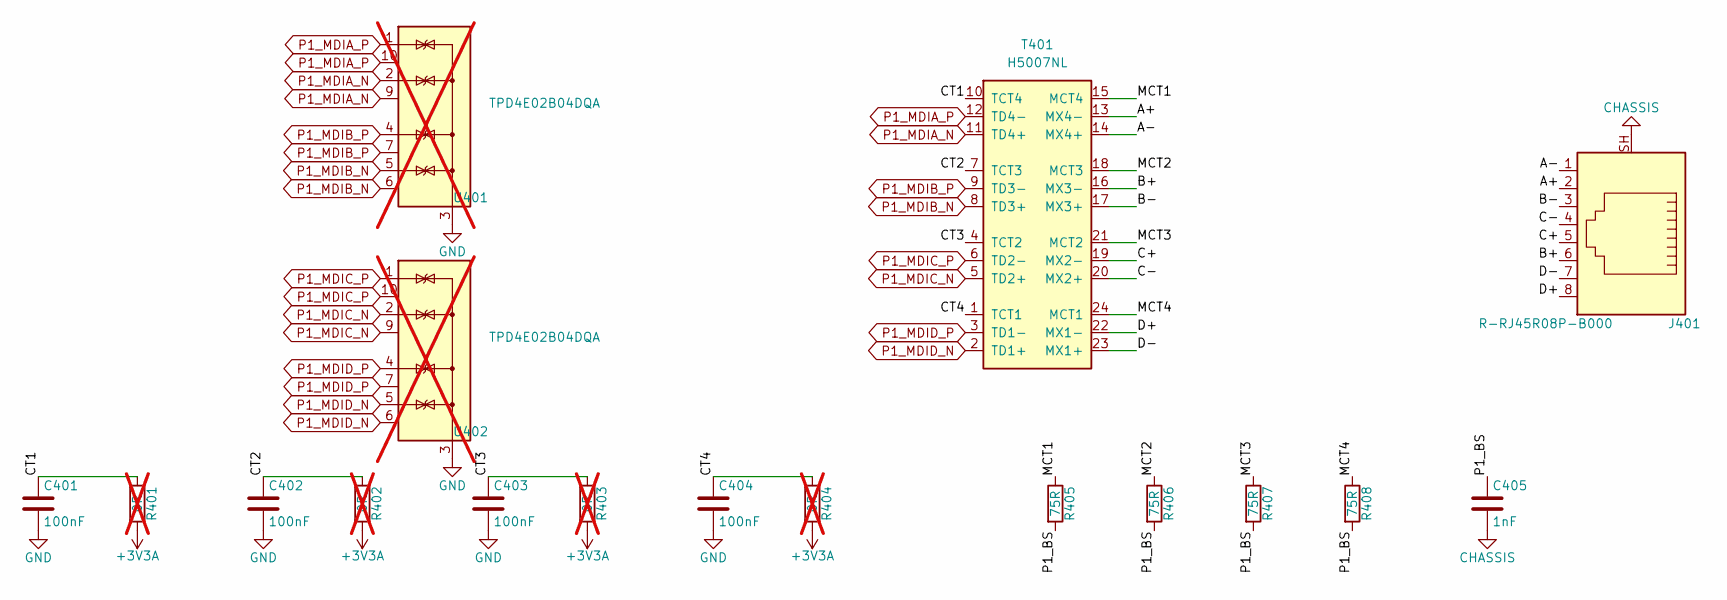
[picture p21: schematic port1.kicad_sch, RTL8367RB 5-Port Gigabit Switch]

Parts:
C401, C402, C403, C404: 100nF; C_0402_1005Metric; Voltage 16V
C405: 1nF; C_1206_3216Metric; Voltage 2kV
J401: R-RJ45R08P-B000; RJ45_Ckmtw_R-RJ45R08P-B000_Horizontal; MPN R-RJ45R08P-B000; LCSC C386756
R401, R402, R403, R404: 0R; R_0402_1005Metric; not fitted
R405, R406, R407, R408: 75R; R_0603_1608Metric; Tolerance 1%
T401: H5007NL; Pulse_H5007NL; MPN H5007NL; LCSC C6384935
U401, U402: TPD4E02B04DQA; USON-10_2.5x1.0mm_P0.5mm; MPN TPD4E02B04DQAR; not fitted

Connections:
+3V3A: R401.2, R402.2, R403.2, R404.2; also elsewhere on the board
/PORT1/A+: J401.2, T401.13 (MX4-)
/PORT1/A-: J401.1, T401.14 (MX4+)
/PORT1/B+: J401.6, T401.16 (MX3-)
/PORT1/B-: J401.3, T401.17 (MX3+)
/PORT1/C+: J401.5, T401.19 (MX2-)
/PORT1/C-: J401.4, T401.20 (MX2+)
/PORT1/CT1: C401.1, R401.1, T401.10 (TCT4)
/PORT1/CT2: C402.1, R402.1, T401.7 (TCT3)
/PORT1/CT3: C403.1, R403.1, T401.4 (TCT2)
/PORT1/CT4: C404.1, R404.1, T401.1 (TCT1)
/PORT1/D+: J401.8, T401.22 (MX1-)
/PORT1/D-: J401.7, T401.23 (MX1+)
/PORT1/MCT1: R405.1, T401.15 (MCT4)
/PORT1/MCT2: R406.1, T401.18 (MCT3)
/PORT1/MCT3: R407.1, T401.21 (MCT2)
/PORT1/MCT4: R408.1, T401.24 (MCT1)
/PORT1/P1_BS: C405.1, R405.2, R406.2, R407.2, R408.2
CHASSIS: C405.2, J401.SH; also elsewhere on the board
GND: C401.2, C402.2, C403.2, C404.2, U401.3 (G), U401.8 (G), U402.3 (G), U402.8 (G); also elsewhere on the board
P1_MDIA_N: T401.11 (TD4+), U401.2 (IO2), U401.9 (NC); also elsewhere on the board
P1_MDIA_P: T401.12 (TD4-), U401.1 (IO1), U401.10 (NC); also elsewhere on the board
P1_MDIB_N: T401.8 (TD3+), U401.5 (IO4), U401.6 (NC); also elsewhere on the board
P1_MDIB_P: T401.9 (TD3-), U401.4 (IO3), U401.7 (NC); also elsewhere on the board
P1_MDIC_N: T401.5 (TD2+), U402.2 (IO2), U402.9 (NC); also elsewhere on the board
P1_MDIC_P: T401.6 (TD2-), U402.1 (IO1), U402.10 (NC); also elsewhere on the board
P1_MDID_N: T401.2 (TD1+), U402.5 (IO4), U402.6 (NC); also elsewhere on the board
P1_MDID_P: T401.3 (TD1-), U402.4 (IO3), U402.7 (NC); also elsewhere on the board

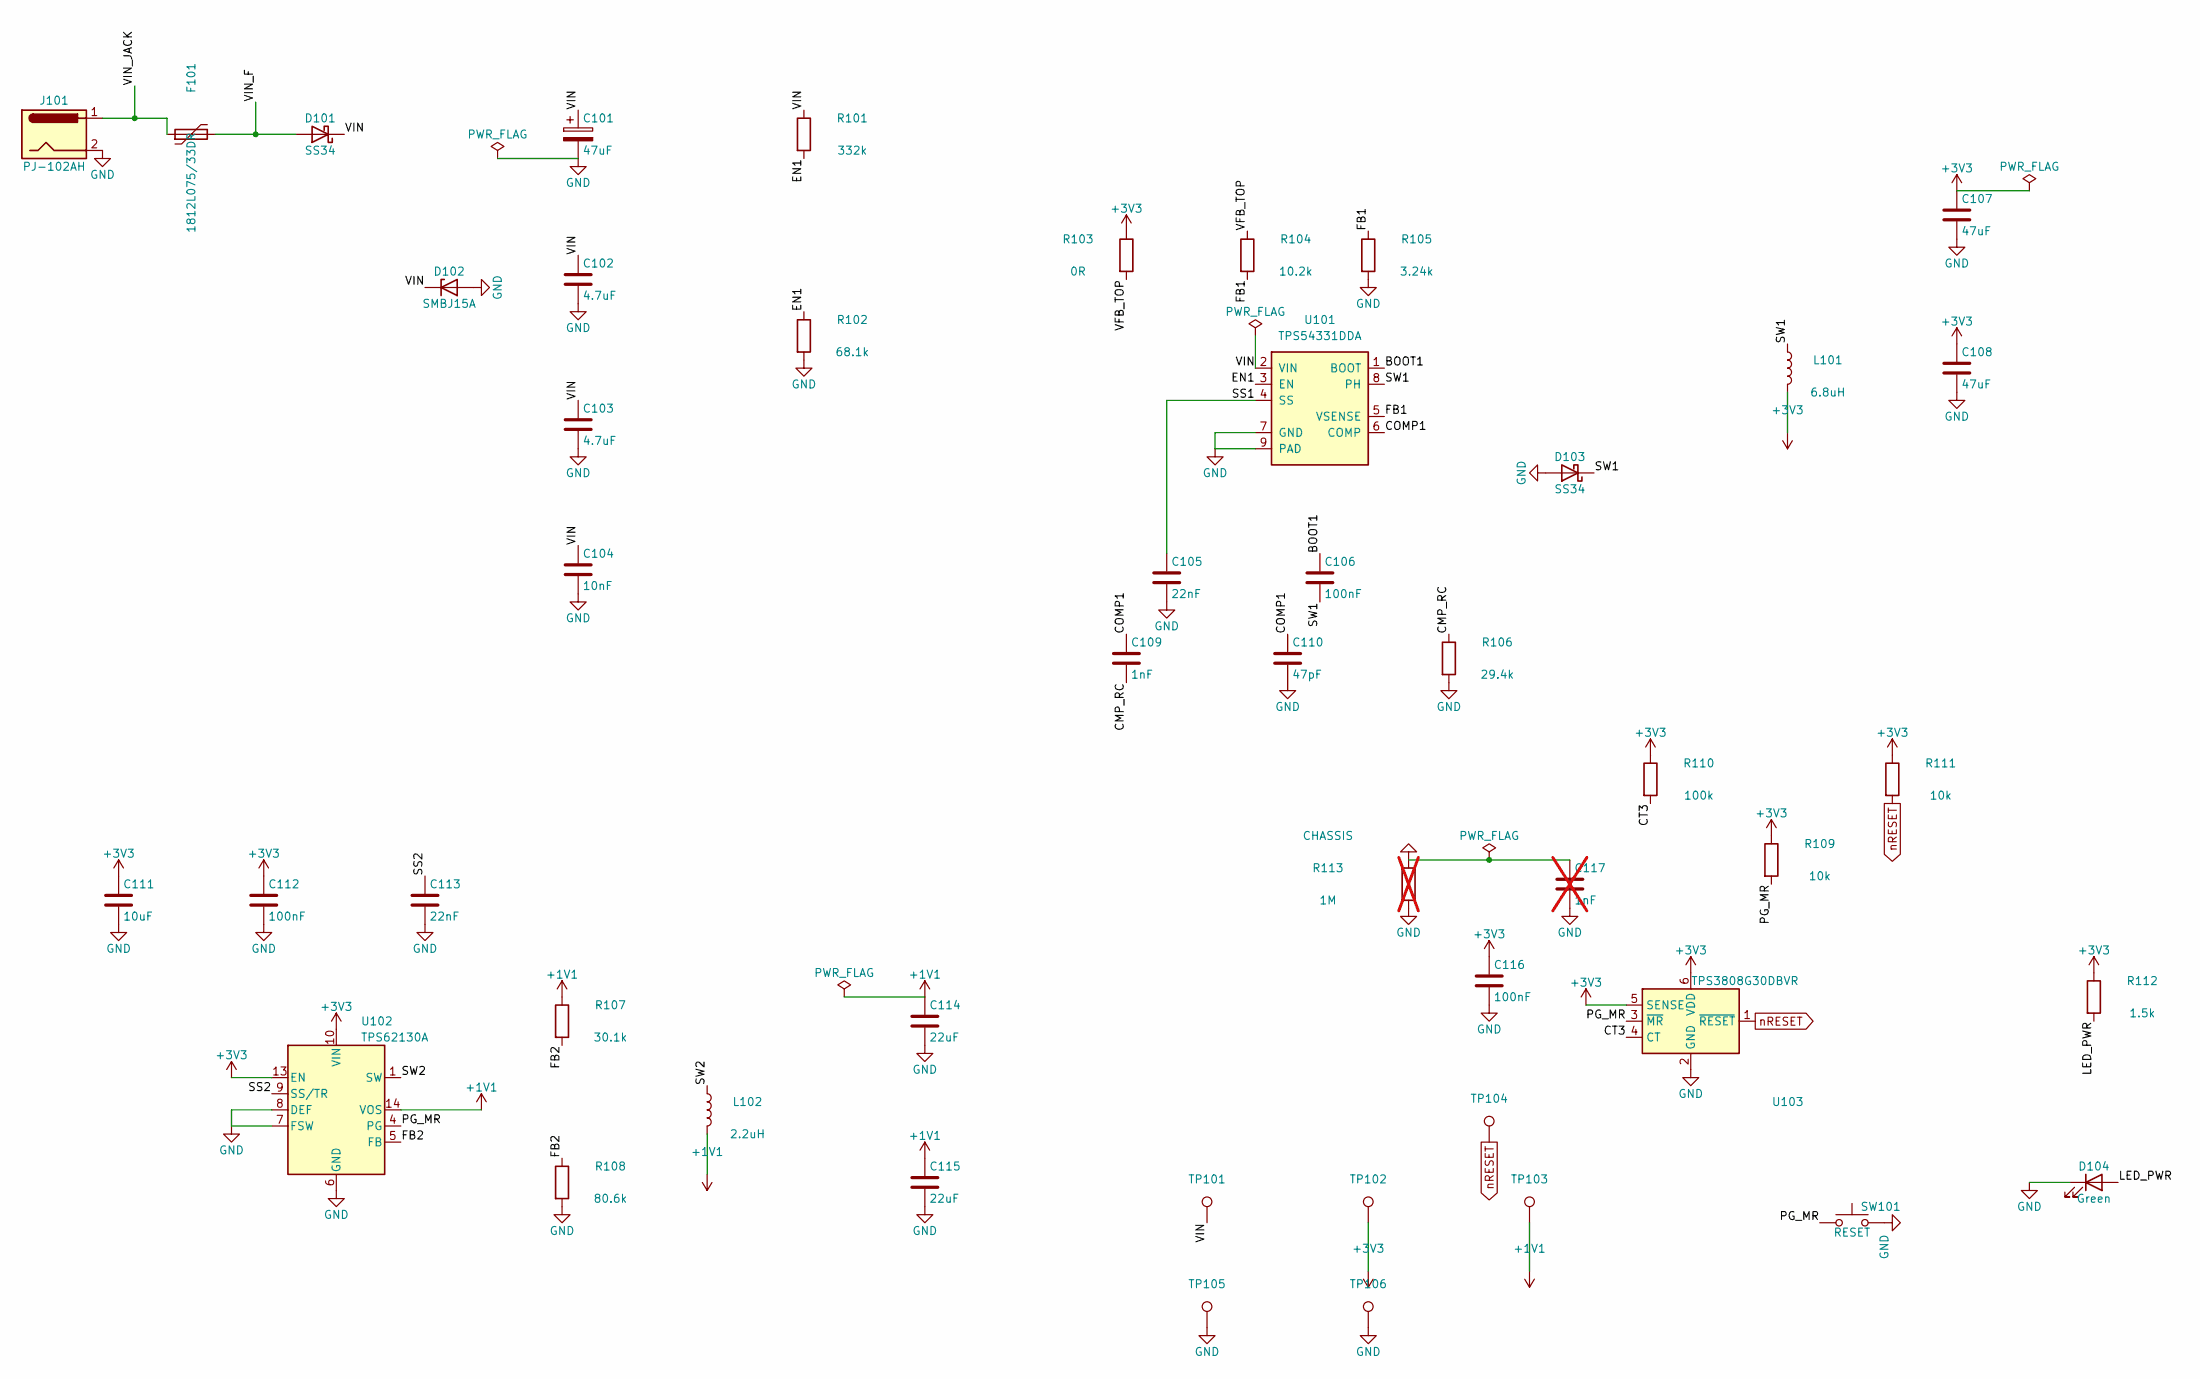
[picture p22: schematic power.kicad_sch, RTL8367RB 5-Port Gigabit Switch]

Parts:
C101: 47uF; CP_Elec_6.3x7.7; Voltage 25V
C102, C103: 4.7uF; C_1206_3216Metric; Voltage 25V
C104: 10nF; C_0603_1608Metric; Voltage 50V
C105, C113: 22nF; C_0603_1608Metric; Voltage 16V
C106: 100nF; C_0603_1608Metric; Voltage 50V
C107, C108: 47uF; C_1210_3225Metric; Voltage 10V
C109: 1nF; C_0603_1608Metric; Voltage 50V
C110: 47pF; C_0603_1608Metric; Voltage 50V
C111: 10uF; C_0805_2012Metric; Voltage 10V
C112, C116: 100nF; C_0402_1005Metric; Voltage 16V
C114, C115: 22uF; C_0805_2012Metric; Voltage 6.3V
C117: 1nF; C_1206_3216Metric; Voltage 2kV; not fitted
D101, D103: SS34; D_SMA; MPN SS34; LCSC C8678
D102: SMBJ15A; D_SMB; MPN SMBJ15A; LCSC C83846
D104: Green; LED_0603_1608Metric; MPN LTST-C193TGKT-5A; LCSC C12065
F101: 1812L075/33DR; Fuse_1812_4532Metric; MPN 1812L075/33DR; LCSC C151170
J101: PJ-102AH; BarrelJack_CUI_PJ-102AH_Horizontal; MPN PJ-102AH; LCSC C3096093
L101: 6.8uH; L_Sunlord_SWPA6045S; MPN SWPA6045S6R8MT; LCSC C57254
L102: 2.2uH; L_Sunlord_SWPA4030S; MPN SWPA4030S2R2MT; LCSC C36409
R101: 332k; R_0603_1608Metric; Tolerance 1%
R102: 68.1k; R_0603_1608Metric; Tolerance 1%
R103: 0R; R_0603_1608Metric
R104: 10.2k; R_0603_1608Metric; Tolerance 1%
R105: 3.24k; R_0603_1608Metric; Tolerance 1%
R106: 29.4k; R_0603_1608Metric; Tolerance 1%
R107: 30.1k; R_0402_1005Metric; Tolerance 1%
R108: 80.6k; R_0402_1005Metric; Tolerance 1%
R109, R111: 10k; R_0402_1005Metric
R110: 100k; R_0402_1005Metric
R112: 1.5k; R_0402_1005Metric
R113: 1M; R_0603_1608Metric; not fitted
SW101: RESET; SW_Push_1P1T_XKB_TS-1187A; MPN TS-1187A-B-A-B; LCSC C318884
TP101: VIN; TestPoint_Pad_D1.5mm
TP102: +3V3; TestPoint_Pad_D1.5mm
TP103: +1V1; TestPoint_Pad_D1.5mm
TP104: nRESET; TestPoint_Pad_D1.5mm
TP105, TP106: GND; TestPoint_Pad_D1.5mm
U101: TPS54331DDA; Texas_HSOP-8-1EP_3.9x4.9mm_P1.27mm_ThermalVias; MPN TPS54331DDAR; LCSC C90761
U102: TPS62130A; VQFN-16-1EP_3x3mm_P0.5mm_EP1.68x1.68mm_ThermalVias; MPN TPS62130ARGTR; LCSC C337502
U103: TPS3808G30DBVR; SOT-23-6; MPN TPS3808G30DBVR; LCSC C189211

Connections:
+1V1: C114.1, C115.1, L102.2, R107.1, TP103.1, U102.14 (VOS); also elsewhere on the board
+3V3: C107.1, C108.1, C111.1, C112.1, C116.1, L101.2, R103.1, R109.1, R110.1, R111.1, R112.1, TP102.1, U102.10 (VIN), U102.11 (VIN), U102.12 (VIN), U102.13 (EN), U103.5 (SENSE), U103.6 (VDD); also elsewhere on the board
/POWER/BOOT1: C106.1, U101.1 (BOOT)
/POWER/CMP_RC: C109.2, R106.1
/POWER/COMP1: C109.1, C110.1, U101.6 (COMP)
/POWER/CT3: R110.2, U103.4 (CT)
/POWER/EN1: R101.2, R102.1, U101.3 (EN)
/POWER/FB1: R104.2, R105.1, U101.5 (VSENSE)
/POWER/FB2: R107.2, R108.1, U102.5 (FB)
/POWER/LED_PWR: D104.2 (A), R112.2
/POWER/PG_MR: R109.2, SW101.1, U102.4 (PG), U103.3 (~MR)
/POWER/SS1: C105.1, U101.4 (SS)
/POWER/SS2: C113.1, U102.9 (SS/TR)
/POWER/SW1: C106.2, D103.1 (K), L101.1, U101.8 (PH)
/POWER/SW2: L102.1, U102.1 (SW), U102.2 (SW), U102.3 (SW)
/POWER/VFB_TOP: R103.2, R104.1
/POWER/VIN: C101.1, C102.1, C103.1, C104.1, D101.1 (K), D102.1 (K), R101.1, TP101.1, U101.2 (VIN)
/POWER/VIN_F: D101.2 (A), F101.2
/POWER/VIN_JACK: F101.1, J101.1
CHASSIS: C117.1, R113.1; also elsewhere on the board
GND: C101.2, C102.2, C103.2, C104.2, C105.2, C107.2, C108.2, C110.2, C111.2, C112.2, C113.2, C114.2, C115.2, C116.2, C117.2, D102.2 (A), D103.2 (A), D104.1 (K), J101.2, R102.2, R105.2, R106.2, R108.2, R113.2, SW101.2, TP105.1, TP106.1, U101.7 (GND), U101.9 (PAD), U102.6 (GND), U102.7 (FSW), U102.8 (DEF), U102.15 (GND), U102.16 (GND), U102.17 (GND), U103.2 (GND); also elsewhere on the board
nRESET: R111.2, TP104.1, U103.1 (~RESET); also elsewhere on the board

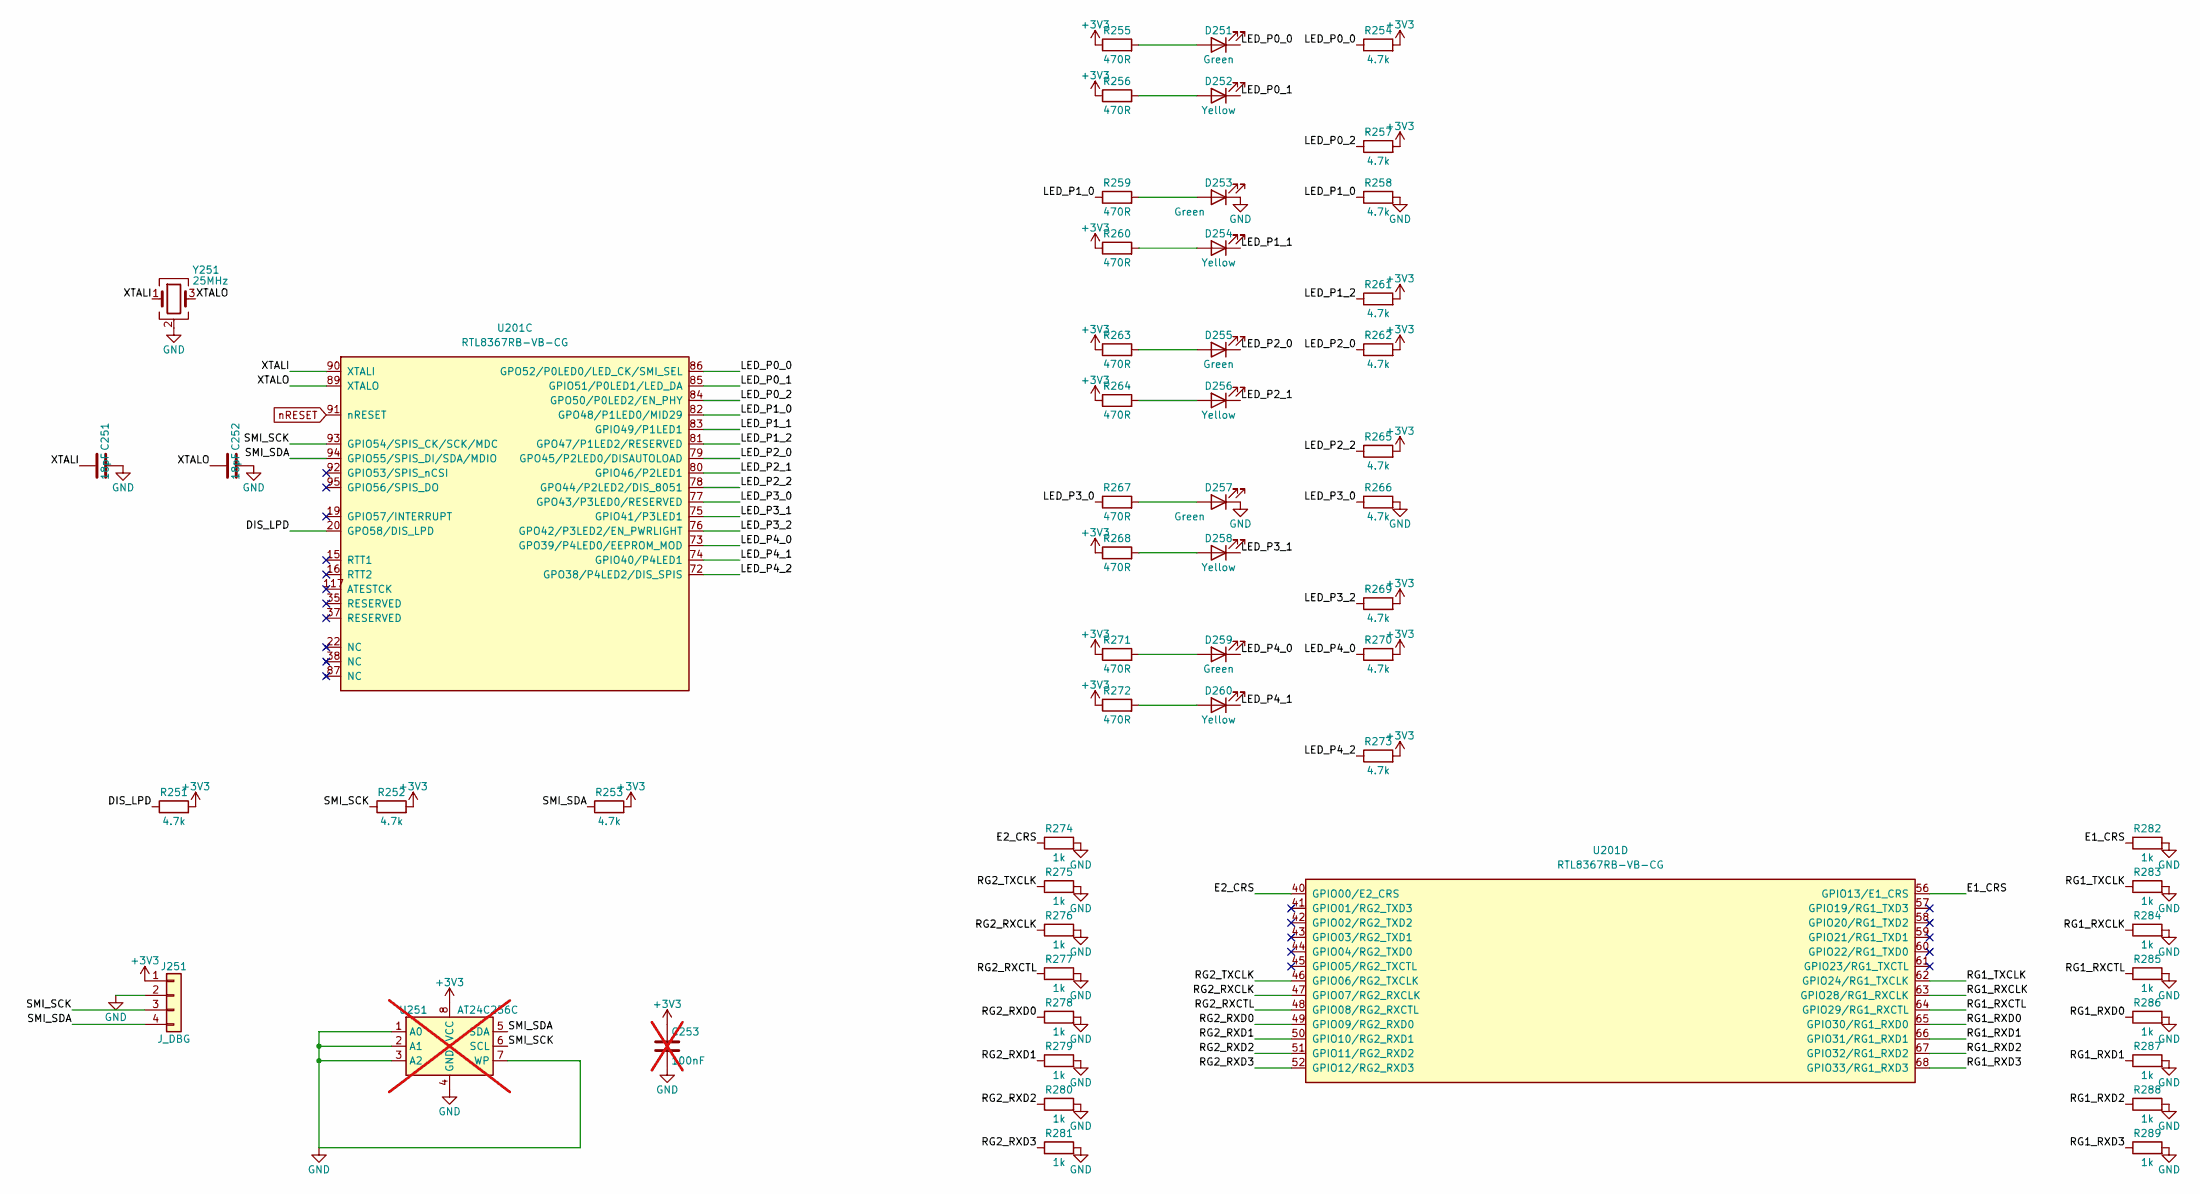
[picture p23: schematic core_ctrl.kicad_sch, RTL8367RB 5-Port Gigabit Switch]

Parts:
C251, C252: 18pF; C_0402_1005Metric; Voltage 50V
C253: 100nF; C_0402_1005Metric; Voltage 16V; not fitted
D251, D253, D255, D257, D259: Green; LED_0603_1608Metric; MPN LTST-C193TGKT-5A; LCSC C12065
D252, D254, D256, D258, D260: Yellow; LED_0603_1608Metric; MPN KT-0603Y; LCSC C2287
J251: J_DBG; PinHeader_1x04_P2.54mm_Vertical
R251, R252, R253, R254, R257, R258, R261, R262, R265, R266, R269, R270, R273: 4.7k; R_0402_1005Metric
R255, R256, R259, R260, R263, R264, R267, R268, R271, R272: 470R; R_0402_1005Metric
R274, R275, R276, R277, R278, R279, R280, R281, R282, R283, R284, R285, R286, R287, R288, R289: 1k; R_0402_1005Metric
U201: RTL8367RB-VB-CG; LQFP-128-1EP_14x14mm_P0.4mm_EP5.5x5.5mm_ThermalVias; MPN RTL8367RB-VB-CG; LCSC C2761412
U251: AT24C256C; SOIC-8_3.9x4.9mm_P1.27mm; MPN AT24C256C-SSHL-T; LCSC C6482; not fitted
Y251: 25MHz; Crystal_SMD_3225-4Pin_3.2x2.5mm; MPN X322525MOB4SI; LCSC C9006

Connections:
+3V3: C253.1, J251.1, R251.2, R252.2, R253.2, R254.2, R255.1, R256.1, R257.2, R260.1, R261.2, R262.2, R263.1, R264.1, R265.2, R268.1, R269.2, R270.2, R271.1, R272.1, R273.2, U251.8 (VCC); also elsewhere on the board
/CORE_CTRL/DIS_LPD: R251.1, U201.20 (GPO58/DIS_LPD)
/CORE_CTRL/E1_CRS: R282.1, U201.56 (GPIO13/E1_CRS)
/CORE_CTRL/E2_CRS: R274.1, U201.40 (GPIO00/E2_CRS)
/CORE_CTRL/LED_P0_0: D251.1 (K), R254.1, U201.86 (GPO52/P0LED0/LED_CK/SMI_SEL)
/CORE_CTRL/LED_P0_1: D252.1 (K), U201.85 (GPIO51/P0LED1/LED_DA)
/CORE_CTRL/LED_P0_2: R257.1, U201.84 (GPO50/P0LED2/EN_PHY)
/CORE_CTRL/LED_P1_0: R258.1, R259.1, U201.82 (GPO48/P1LED0/MID29)
/CORE_CTRL/LED_P1_1: D254.1 (K), U201.83 (GPIO49/P1LED1)
/CORE_CTRL/LED_P1_2: R261.1, U201.81 (GPO47/P1LED2/RESERVED)
/CORE_CTRL/LED_P2_0: D255.1 (K), R262.1, U201.79 (GPO45/P2LED0/DISAUTOLOAD)
/CORE_CTRL/LED_P2_1: D256.1 (K), U201.80 (GPIO46/P2LED1)
/CORE_CTRL/LED_P2_2: R265.1, U201.78 (GPO44/P2LED2/DIS_8051)
/CORE_CTRL/LED_P3_0: R266.1, R267.1, U201.77 (GPO43/P3LED0/RESERVED)
/CORE_CTRL/LED_P3_1: D258.1 (K), U201.75 (GPIO41/P3LED1)
/CORE_CTRL/LED_P3_2: R269.1, U201.76 (GPO42/P3LED2/EN_PWRLIGHT)
/CORE_CTRL/LED_P4_0: D259.1 (K), R270.1, U201.73 (GPO39/P4LED0/EEPROM_MOD)
/CORE_CTRL/LED_P4_1: D260.1 (K), U201.74 (GPIO40/P4LED1)
/CORE_CTRL/LED_P4_2: R273.1, U201.72 (GPO38/P4LED2/DIS_SPIS)
/CORE_CTRL/RG1_RXCLK: R284.1, U201.63 (GPIO28/RG1_RXCLK)
/CORE_CTRL/RG1_RXCTL: R285.1, U201.64 (GPIO29/RG1_RXCTL)
/CORE_CTRL/RG1_RXD0: R286.1, U201.65 (GPIO30/RG1_RXD0)
/CORE_CTRL/RG1_RXD1: R287.1, U201.66 (GPIO31/RG1_RXD1)
/CORE_CTRL/RG1_RXD2: R288.1, U201.67 (GPIO32/RG1_RXD2)
/CORE_CTRL/RG1_RXD3: R289.1, U201.68 (GPIO33/RG1_RXD3)
/CORE_CTRL/RG1_TXCLK: R283.1, U201.62 (GPIO24/RG1_TXCLK)
/CORE_CTRL/RG2_RXCLK: R276.1, U201.47 (GPIO07/RG2_RXCLK)
/CORE_CTRL/RG2_RXCTL: R277.1, U201.48 (GPIO08/RG2_RXCTL)
/CORE_CTRL/RG2_RXD0: R278.1, U201.49 (GPIO09/RG2_RXD0)
/CORE_CTRL/RG2_RXD1: R279.1, U201.50 (GPIO10/RG2_RXD1)
/CORE_CTRL/RG2_RXD2: R280.1, U201.51 (GPIO11/RG2_RXD2)
/CORE_CTRL/RG2_RXD3: R281.1, U201.52 (GPIO12/RG2_RXD3)
/CORE_CTRL/RG2_TXCLK: R275.1, U201.46 (GPIO06/RG2_TXCLK)
/CORE_CTRL/SMI_SCK: J251.3, R252.1, U201.93 (GPIO54/SPIS_CK/SCK/MDC), U251.6 (SCL)
/CORE_CTRL/SMI_SDA: J251.4, R253.1, U201.94 (GPIO55/SPIS_DI/SDA/MDIO), U251.5 (SDA)
/CORE_CTRL/XTALI: C251.1, U201.90 (XTALI), Y251.1
/CORE_CTRL/XTALO: C252.1, U201.89 (XTALO), Y251.3
GND: C251.2, C252.2, C253.2, D253.1 (K), D257.1 (K), J251.2, R258.2, R266.2, R274.2, R275.2, R276.2, R277.2, R278.2, R279.2, R280.2, R281.2, R282.2, R283.2, R284.2, R285.2, R286.2, R287.2, R288.2, R289.2, U251.1 (A0), U251.2 (A1), U251.3 (A2), U251.4 (GND), U251.7 (WP), Y251.2 (G), Y251.4 (G); also elsewhere on the board
unnamed: D251.2 (A), R255.2
unnamed: D252.2 (A), R256.2
unnamed: D253.2 (A), R259.2
unnamed: D254.2 (A), R260.2
unnamed: D255.2 (A), R263.2
unnamed: D256.2 (A), R264.2
unnamed: D257.2 (A), R267.2
unnamed: D258.2 (A), R268.2
unnamed: D259.2 (A), R271.2
unnamed: D260.2 (A), R272.2
nRESET: U201.91 (nRESET); also elsewhere on the board

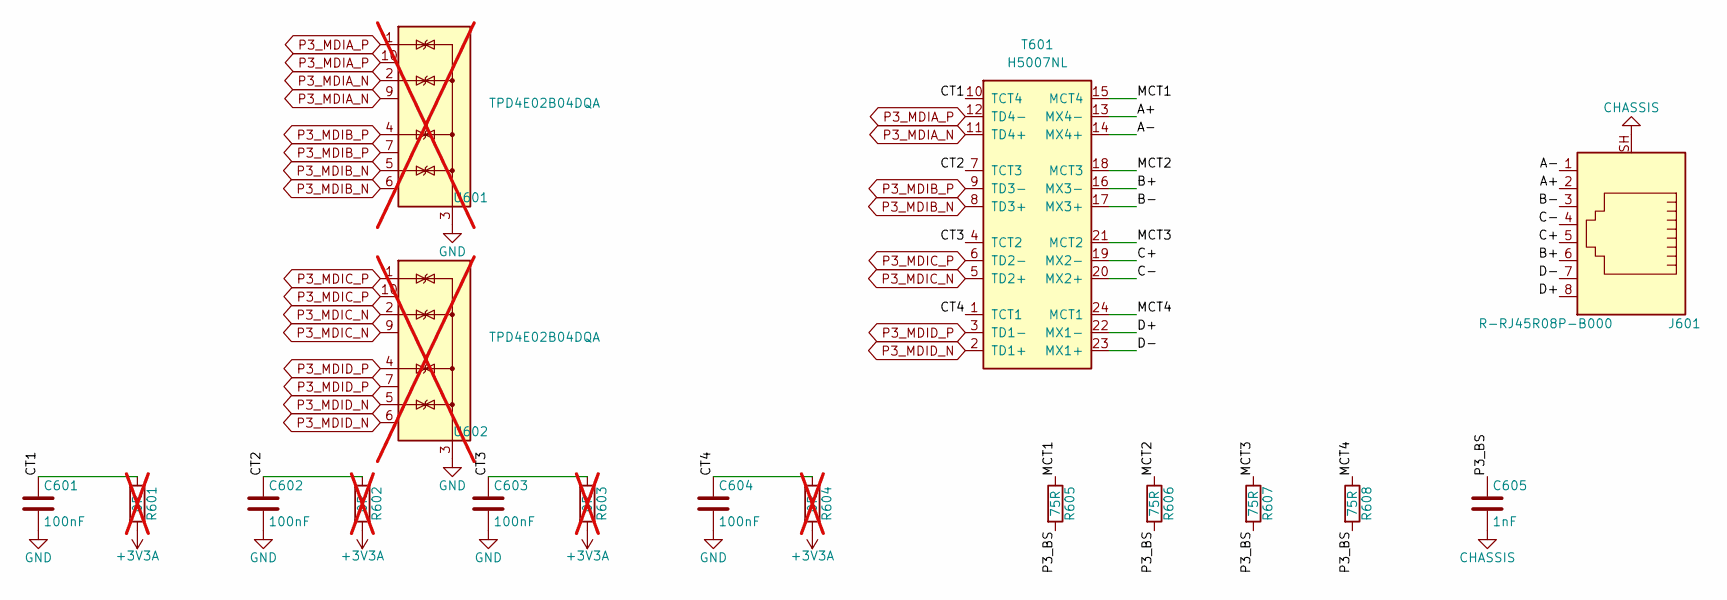
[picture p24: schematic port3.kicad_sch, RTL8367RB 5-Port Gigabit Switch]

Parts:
C601, C602, C603, C604: 100nF; C_0402_1005Metric; Voltage 16V
C605: 1nF; C_1206_3216Metric; Voltage 2kV
J601: R-RJ45R08P-B000; RJ45_Ckmtw_R-RJ45R08P-B000_Horizontal; MPN R-RJ45R08P-B000; LCSC C386756
R601, R602, R603, R604: 0R; R_0402_1005Metric; not fitted
R605, R606, R607, R608: 75R; R_0603_1608Metric; Tolerance 1%
T601: H5007NL; Pulse_H5007NL; MPN H5007NL; LCSC C6384935
U601, U602: TPD4E02B04DQA; USON-10_2.5x1.0mm_P0.5mm; MPN TPD4E02B04DQAR; not fitted

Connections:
+3V3A: R601.2, R602.2, R603.2, R604.2; also elsewhere on the board
/PORT3/A+: J601.2, T601.13 (MX4-)
/PORT3/A-: J601.1, T601.14 (MX4+)
/PORT3/B+: J601.6, T601.16 (MX3-)
/PORT3/B-: J601.3, T601.17 (MX3+)
/PORT3/C+: J601.5, T601.19 (MX2-)
/PORT3/C-: J601.4, T601.20 (MX2+)
/PORT3/CT1: C601.1, R601.1, T601.10 (TCT4)
/PORT3/CT2: C602.1, R602.1, T601.7 (TCT3)
/PORT3/CT3: C603.1, R603.1, T601.4 (TCT2)
/PORT3/CT4: C604.1, R604.1, T601.1 (TCT1)
/PORT3/D+: J601.8, T601.22 (MX1-)
/PORT3/D-: J601.7, T601.23 (MX1+)
/PORT3/MCT1: R605.1, T601.15 (MCT4)
/PORT3/MCT2: R606.1, T601.18 (MCT3)
/PORT3/MCT3: R607.1, T601.21 (MCT2)
/PORT3/MCT4: R608.1, T601.24 (MCT1)
/PORT3/P3_BS: C605.1, R605.2, R606.2, R607.2, R608.2
CHASSIS: C605.2, J601.SH; also elsewhere on the board
GND: C601.2, C602.2, C603.2, C604.2, U601.3 (G), U601.8 (G), U602.3 (G), U602.8 (G); also elsewhere on the board
P3_MDIA_N: T601.11 (TD4+), U601.2 (IO2), U601.9 (NC); also elsewhere on the board
P3_MDIA_P: T601.12 (TD4-), U601.1 (IO1), U601.10 (NC); also elsewhere on the board
P3_MDIB_N: T601.8 (TD3+), U601.5 (IO4), U601.6 (NC); also elsewhere on the board
P3_MDIB_P: T601.9 (TD3-), U601.4 (IO3), U601.7 (NC); also elsewhere on the board
P3_MDIC_N: T601.5 (TD2+), U602.2 (IO2), U602.9 (NC); also elsewhere on the board
P3_MDIC_P: T601.6 (TD2-), U602.1 (IO1), U602.10 (NC); also elsewhere on the board
P3_MDID_N: T601.2 (TD1+), U602.5 (IO4), U602.6 (NC); also elsewhere on the board
P3_MDID_P: T601.3 (TD1-), U602.4 (IO3), U602.7 (NC); also elsewhere on the board

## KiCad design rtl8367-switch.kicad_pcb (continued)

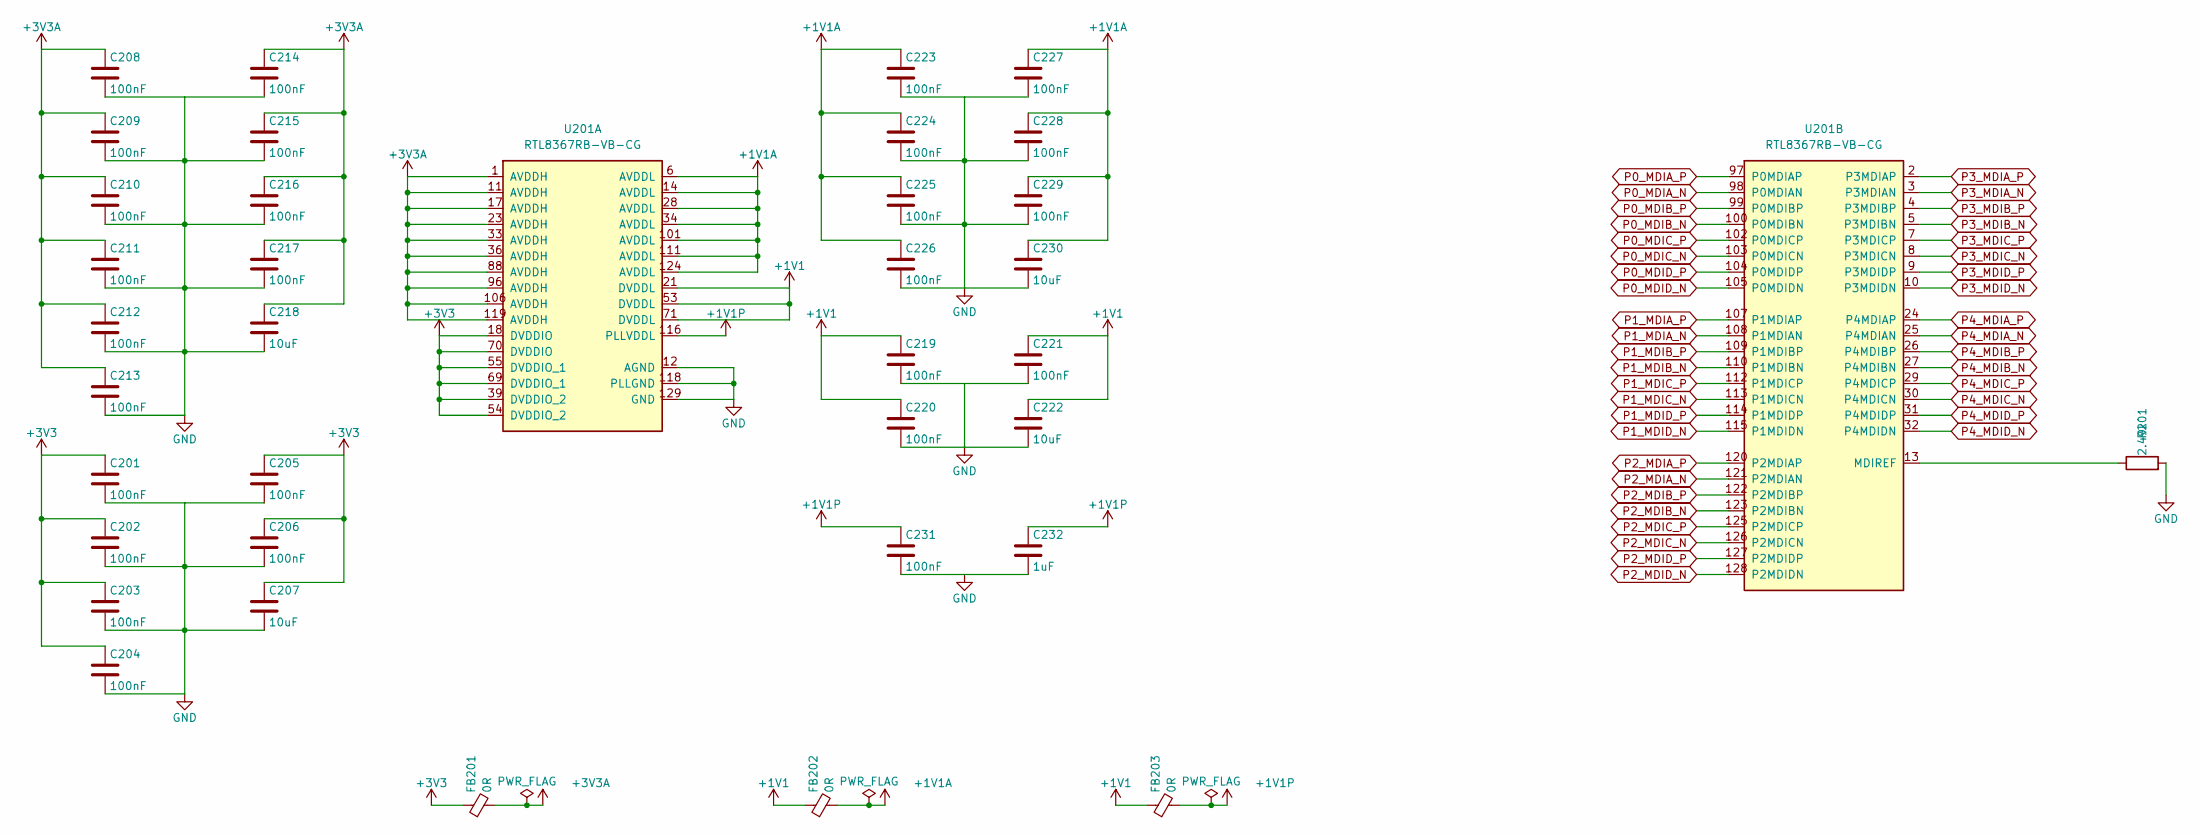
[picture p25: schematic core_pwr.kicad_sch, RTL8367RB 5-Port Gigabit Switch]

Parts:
C201, C202, C203, C204, C205, C206, C208, C209, C210, C211, C212, C213, C214, C215, C216, C217, C219, C220, C221, C223, C224, C225, C226, C227, C228, C229, C231: 100nF; C_0402_1005Metric; Voltage 16V
C207, C218, C222, C230: 10uF; C_0805_2012Metric; Voltage 10V
C232: 1uF; C_0603_1608Metric; Voltage 16V
FB201, FB202, FB203: 0R; R_0603_1608Metric
R201: 2.49k; R_0402_1005Metric; Tolerance 1%
U201: RTL8367RB-VB-CG; LQFP-128-1EP_14x14mm_P0.4mm_EP5.5x5.5mm_ThermalVias; MPN RTL8367RB-VB-CG; LCSC C2761412

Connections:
+1V1: C219.1, C220.1, C221.1, C222.1, FB202.1, FB203.1, U201.21 (DVDDL), U201.53 (DVDDL), U201.71 (DVDDL); also elsewhere on the board
+1V1A: C223.1, C224.1, C225.1, C226.1, C227.1, C228.1, C229.1, C230.1, FB202.2, U201.6 (AVDDL), U201.14 (AVDDL), U201.28 (AVDDL), U201.34 (AVDDL), U201.101 (AVDDL), U201.111 (AVDDL), U201.124 (AVDDL)
+1V1P: C231.1, C232.1, FB203.2, U201.116 (PLLVDDL)
+3V3: C201.1, C202.1, C203.1, C204.1, C205.1, C206.1, C207.1, FB201.1, U201.18 (DVDDIO), U201.39 (DVDDIO_2), U201.54 (DVDDIO_2), U201.55 (DVDDIO_1), U201.69 (DVDDIO_1), U201.70 (DVDDIO); also elsewhere on the board
+3V3A: C208.1, C209.1, C210.1, C211.1, C212.1, C213.1, C214.1, C215.1, C216.1, C217.1, C218.1, FB201.2, U201.1 (AVDDH), U201.11 (AVDDH), U201.17 (AVDDH), U201.23 (AVDDH), U201.33 (AVDDH), U201.36 (AVDDH), U201.88 (AVDDH), U201.96 (AVDDH), U201.106 (AVDDH), U201.119 (AVDDH); also elsewhere on the board
GND: C201.2, C202.2, C203.2, C204.2, C205.2, C206.2, C207.2, C208.2, C209.2, C210.2, C211.2, C212.2, C213.2, C214.2, C215.2, C216.2, C217.2, C218.2, C219.2, C220.2, C221.2, C222.2, C223.2, C224.2, C225.2, C226.2, C227.2, C228.2, C229.2, C230.2, C231.2, C232.2, R201.2, U201.12 (AGND), U201.118 (PLLGND), U201.129 (GND); also elsewhere on the board
unnamed: R201.1, U201.13 (MDIREF)
P0_MDIA_N: U201.98 (P0MDIAN); also elsewhere on the board
P0_MDIA_P: U201.97 (P0MDIAP); also elsewhere on the board
P0_MDIB_N: U201.100 (P0MDIBN); also elsewhere on the board
P0_MDIB_P: U201.99 (P0MDIBP); also elsewhere on the board
P0_MDIC_N: U201.103 (P0MDICN); also elsewhere on the board
P0_MDIC_P: U201.102 (P0MDICP); also elsewhere on the board
P0_MDID_N: U201.105 (P0MDIDN); also elsewhere on the board
P0_MDID_P: U201.104 (P0MDIDP); also elsewhere on the board
P1_MDIA_N: U201.108 (P1MDIAN); also elsewhere on the board
P1_MDIA_P: U201.107 (P1MDIAP); also elsewhere on the board
P1_MDIB_N: U201.110 (P1MDIBN); also elsewhere on the board
P1_MDIB_P: U201.109 (P1MDIBP); also elsewhere on the board
P1_MDIC_N: U201.113 (P1MDICN); also elsewhere on the board
P1_MDIC_P: U201.112 (P1MDICP); also elsewhere on the board
P1_MDID_N: U201.115 (P1MDIDN); also elsewhere on the board
P1_MDID_P: U201.114 (P1MDIDP); also elsewhere on the board
P2_MDIA_N: U201.121 (P2MDIAN); also elsewhere on the board
P2_MDIA_P: U201.120 (P2MDIAP); also elsewhere on the board
P2_MDIB_N: U201.123 (P2MDIBN); also elsewhere on the board
P2_MDIB_P: U201.122 (P2MDIBP); also elsewhere on the board
P2_MDIC_N: U201.126 (P2MDICN); also elsewhere on the board
P2_MDIC_P: U201.125 (P2MDICP); also elsewhere on the board
P2_MDID_N: U201.128 (P2MDIDN); also elsewhere on the board
P2_MDID_P: U201.127 (P2MDIDP); also elsewhere on the board
P3_MDIA_N: U201.3 (P3MDIAN); also elsewhere on the board
P3_MDIA_P: U201.2 (P3MDIAP); also elsewhere on the board
P3_MDIB_N: U201.5 (P3MDIBN); also elsewhere on the board
P3_MDIB_P: U201.4 (P3MDIBP); also elsewhere on the board
P3_MDIC_N: U201.8 (P3MDICN); also elsewhere on the board
P3_MDIC_P: U201.7 (P3MDICP); also elsewhere on the board
P3_MDID_N: U201.10 (P3MDIDN); also elsewhere on the board
P3_MDID_P: U201.9 (P3MDIDP); also elsewhere on the board
P4_MDIA_N: U201.25 (P4MDIAN); also elsewhere on the board
P4_MDIA_P: U201.24 (P4MDIAP); also elsewhere on the board
P4_MDIB_N: U201.27 (P4MDIBN); also elsewhere on the board
P4_MDIB_P: U201.26 (P4MDIBP); also elsewhere on the board
P4_MDIC_N: U201.30 (P4MDICN); also elsewhere on the board
P4_MDIC_P: U201.29 (P4MDICP); also elsewhere on the board
P4_MDID_N: U201.32 (P4MDIDN); also elsewhere on the board
P4_MDID_P: U201.31 (P4MDIDP); also elsewhere on the board

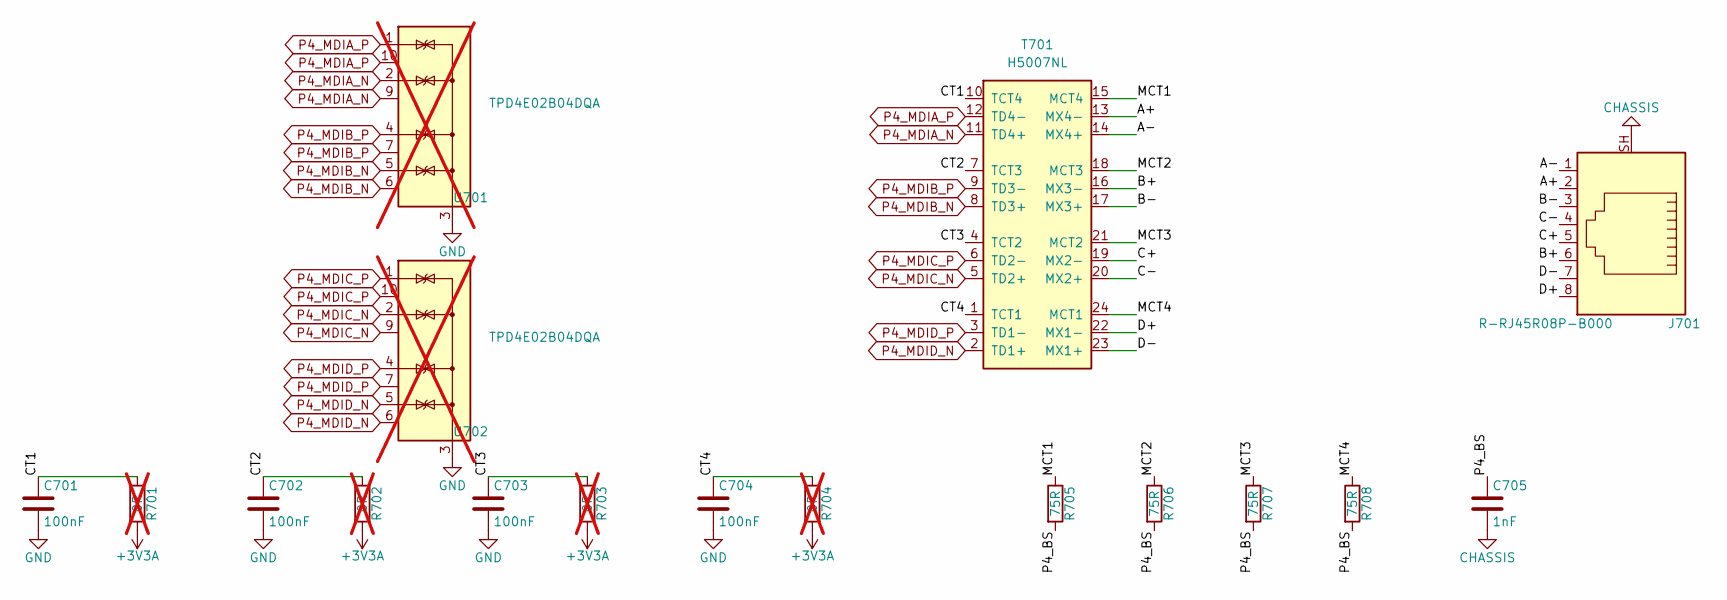
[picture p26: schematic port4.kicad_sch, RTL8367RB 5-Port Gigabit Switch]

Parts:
C701, C702, C703, C704: 100nF; C_0402_1005Metric; Voltage 16V
C705: 1nF; C_1206_3216Metric; Voltage 2kV
J701: R-RJ45R08P-B000; RJ45_Ckmtw_R-RJ45R08P-B000_Horizontal; MPN R-RJ45R08P-B000; LCSC C386756
R701, R702, R703, R704: 0R; R_0402_1005Metric; not fitted
R705, R706, R707, R708: 75R; R_0603_1608Metric; Tolerance 1%
T701: H5007NL; Pulse_H5007NL; MPN H5007NL; LCSC C6384935
U701, U702: TPD4E02B04DQA; USON-10_2.5x1.0mm_P0.5mm; MPN TPD4E02B04DQAR; not fitted

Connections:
+3V3A: R701.2, R702.2, R703.2, R704.2; also elsewhere on the board
/PORT4/A+: J701.2, T701.13 (MX4-)
/PORT4/A-: J701.1, T701.14 (MX4+)
/PORT4/B+: J701.6, T701.16 (MX3-)
/PORT4/B-: J701.3, T701.17 (MX3+)
/PORT4/C+: J701.5, T701.19 (MX2-)
/PORT4/C-: J701.4, T701.20 (MX2+)
/PORT4/CT1: C701.1, R701.1, T701.10 (TCT4)
/PORT4/CT2: C702.1, R702.1, T701.7 (TCT3)
/PORT4/CT3: C703.1, R703.1, T701.4 (TCT2)
/PORT4/CT4: C704.1, R704.1, T701.1 (TCT1)
/PORT4/D+: J701.8, T701.22 (MX1-)
/PORT4/D-: J701.7, T701.23 (MX1+)
/PORT4/MCT1: R705.1, T701.15 (MCT4)
/PORT4/MCT2: R706.1, T701.18 (MCT3)
/PORT4/MCT3: R707.1, T701.21 (MCT2)
/PORT4/MCT4: R708.1, T701.24 (MCT1)
/PORT4/P4_BS: C705.1, R705.2, R706.2, R707.2, R708.2
CHASSIS: C705.2, J701.SH; also elsewhere on the board
GND: C701.2, C702.2, C703.2, C704.2, U701.3 (G), U701.8 (G), U702.3 (G), U702.8 (G); also elsewhere on the board
P4_MDIA_N: T701.11 (TD4+), U701.2 (IO2), U701.9 (NC); also elsewhere on the board
P4_MDIA_P: T701.12 (TD4-), U701.1 (IO1), U701.10 (NC); also elsewhere on the board
P4_MDIB_N: T701.8 (TD3+), U701.5 (IO4), U701.6 (NC); also elsewhere on the board
P4_MDIB_P: T701.9 (TD3-), U701.4 (IO3), U701.7 (NC); also elsewhere on the board
P4_MDIC_N: T701.5 (TD2+), U702.2 (IO2), U702.9 (NC); also elsewhere on the board
P4_MDIC_P: T701.6 (TD2-), U702.1 (IO1), U702.10 (NC); also elsewhere on the board
P4_MDID_N: T701.2 (TD1+), U702.5 (IO4), U702.6 (NC); also elsewhere on the board
P4_MDID_P: T701.3 (TD1-), U702.4 (IO3), U702.7 (NC); also elsewhere on the board

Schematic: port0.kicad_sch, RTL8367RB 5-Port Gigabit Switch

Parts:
C301, C302, C303, C304: 100nF; C_0402_1005Metric; Voltage 16V
C305: 1nF; C_1206_3216Metric; Voltage 2kV
J301: R-RJ45R08P-B000; RJ45_Ckmtw_R-RJ45R08P-B000_Horizontal; MPN R-RJ45R08P-B000; LCSC C386756
R301, R302, R303, R304: 0R; R_0402_1005Metric; not fitted
R305, R306, R307, R308: 75R; R_0603_1608Metric; Tolerance 1%
T301: H5007NL; Pulse_H5007NL; MPN H5007NL; LCSC C6384935
U301, U302: TPD4E02B04DQA; USON-10_2.5x1.0mm_P0.5mm; MPN TPD4E02B04DQAR; not fitted

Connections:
+3V3A: R301.2, R302.2, R303.2, R304.2; also elsewhere on the board
/PORT0/A+: J301.2, T301.13 (MX4-)
/PORT0/A-: J301.1, T301.14 (MX4+)
/PORT0/B+: J301.6, T301.16 (MX3-)
/PORT0/B-: J301.3, T301.17 (MX3+)
/PORT0/C+: J301.5, T301.19 (MX2-)
/PORT0/C-: J301.4, T301.20 (MX2+)
/PORT0/CT1: C301.1, R301.1, T301.10 (TCT4)
/PORT0/CT2: C302.1, R302.1, T301.7 (TCT3)
/PORT0/CT3: C303.1, R303.1, T301.4 (TCT2)
/PORT0/CT4: C304.1, R304.1, T301.1 (TCT1)
/PORT0/D+: J301.8, T301.22 (MX1-)
/PORT0/D-: J301.7, T301.23 (MX1+)
/PORT0/MCT1: R305.1, T301.15 (MCT4)
/PORT0/MCT2: R306.1, T301.18 (MCT3)
/PORT0/MCT3: R307.1, T301.21 (MCT2)
/PORT0/MCT4: R308.1, T301.24 (MCT1)
/PORT0/P0_BS: C305.1, R305.2, R306.2, R307.2, R308.2
CHASSIS: C305.2, J301.SH; also elsewhere on the board
GND: C301.2, C302.2, C303.2, C304.2, U301.3 (G), U301.8 (G), U302.3 (G), U302.8 (G); also elsewhere on the board
P0_MDIA_N: T301.11 (TD4+), U301.2 (IO2), U301.9 (NC); also elsewhere on the board
P0_MDIA_P: T301.12 (TD4-), U301.1 (IO1), U301.10 (NC); also elsewhere on the board
P0_MDIB_N: T301.8 (TD3+), U301.5 (IO4), U301.6 (NC); also elsewhere on the board
P0_MDIB_P: T301.9 (TD3-), U301.4 (IO3), U301.7 (NC); also elsewhere on the board
P0_MDIC_N: T301.5 (TD2+), U302.2 (IO2), U302.9 (NC); also elsewhere on the board
P0_MDIC_P: T301.6 (TD2-), U302.1 (IO1), U302.10 (NC); also elsewhere on the board
P0_MDID_N: T301.2 (TD1+), U302.5 (IO4), U302.6 (NC); also elsewhere on the board
P0_MDID_P: T301.3 (TD1-), U302.4 (IO3), U302.7 (NC); also elsewhere on the board

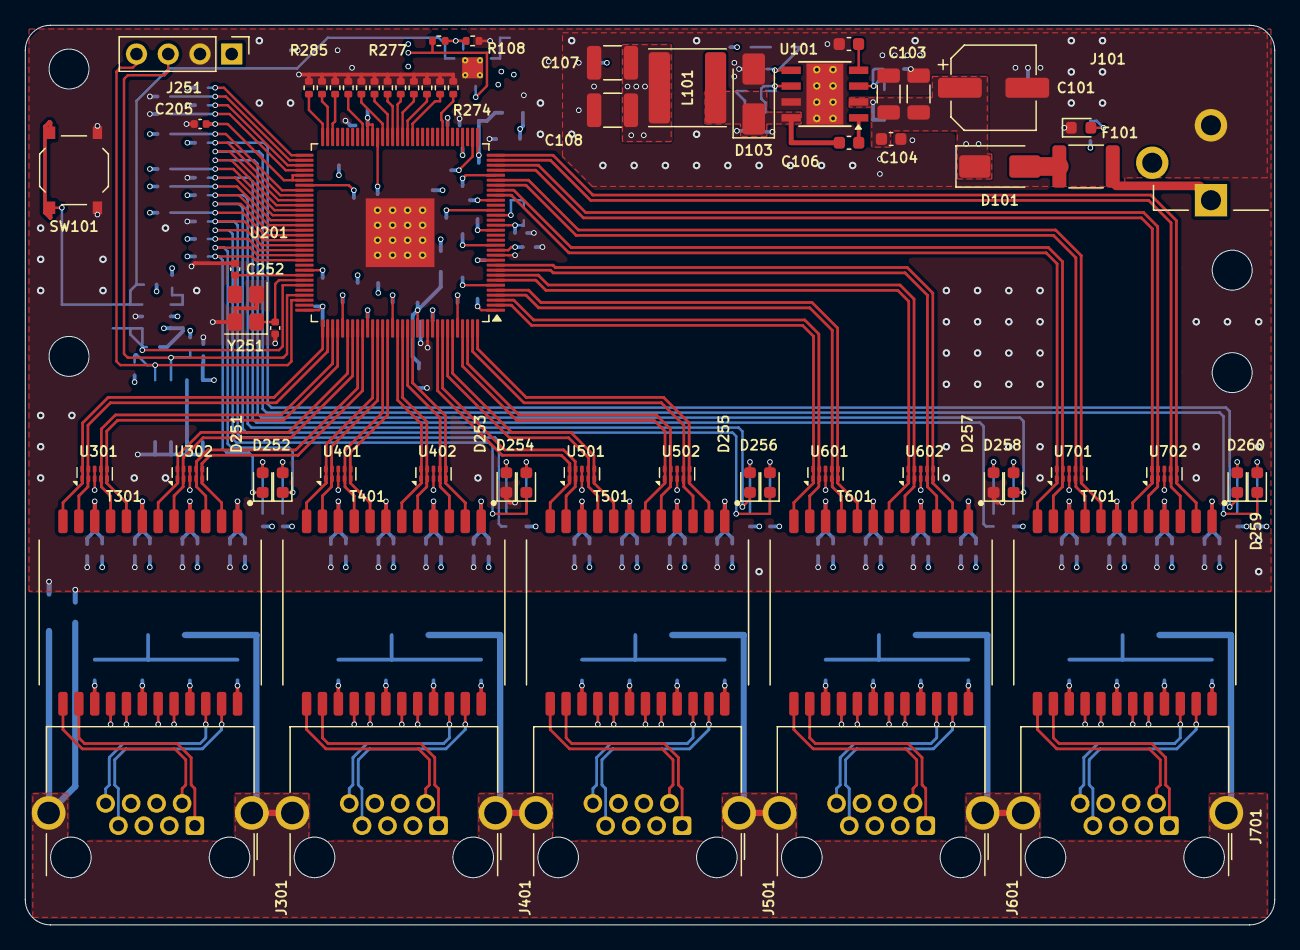
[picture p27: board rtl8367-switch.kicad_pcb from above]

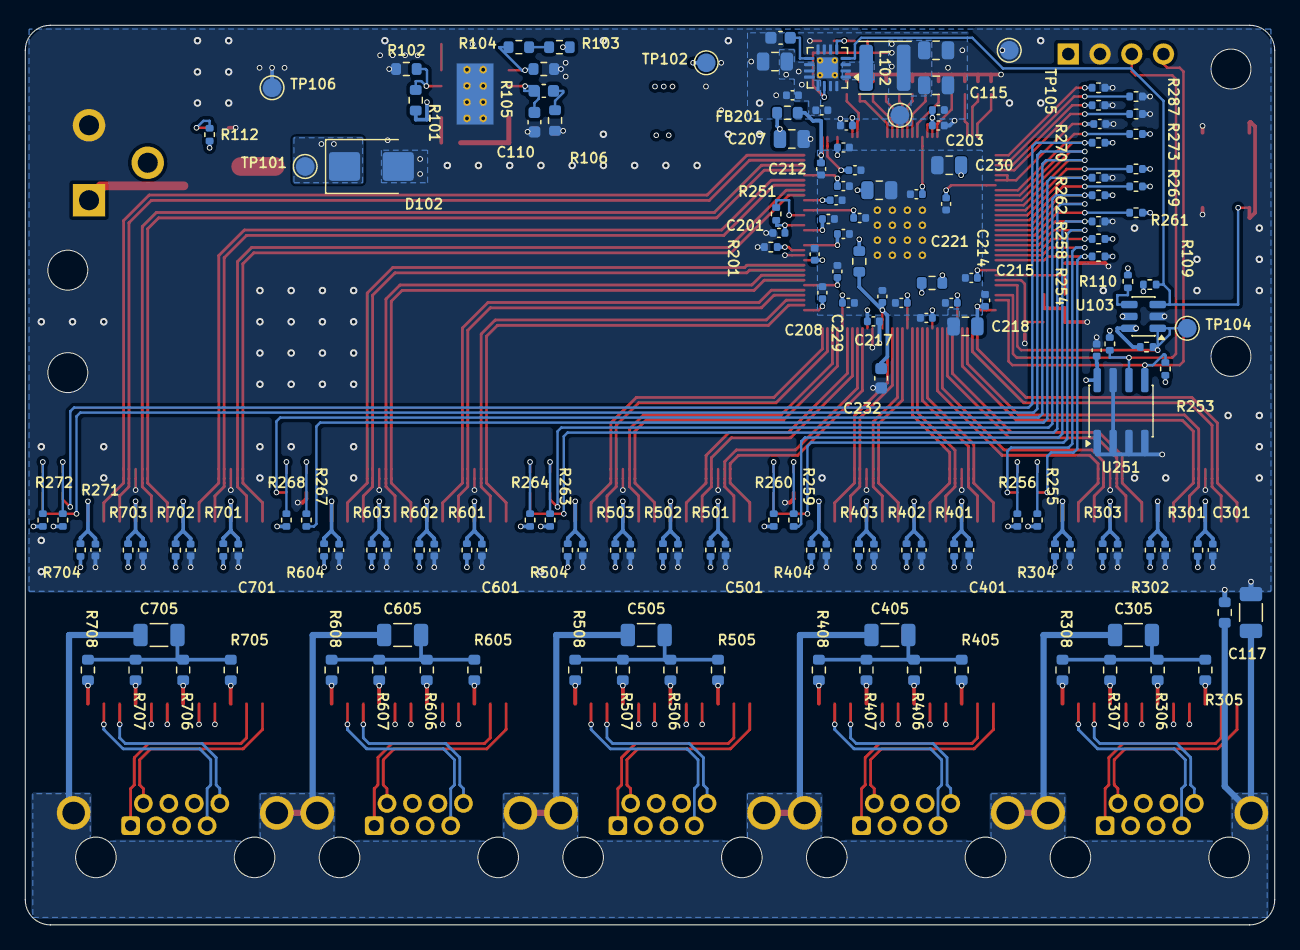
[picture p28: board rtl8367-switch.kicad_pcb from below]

Board: 4 copper layers, 100.0 x 72.0 mm, 229 parts (159 on the bottom side), 197 nets.

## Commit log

2026-09-27 RTL8367 Switch v0.1.0: five-port gigabit unmanaged switch (RTL8367RB), 4-layer 100 x 72 mm
    [core_ctrl.kicad_sch, core_pwr.kicad_sch, port0.kicad_sch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]
2026-09-27 Docs: assembly and bring-up notes in the README
2026-10-01 Docs: add a photo of the earlier prototype board
